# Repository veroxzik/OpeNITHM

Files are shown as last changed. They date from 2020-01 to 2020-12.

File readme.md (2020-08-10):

# OpeNITHM

This repository contails files related to OpeNITHM.

Firmware, schematics, board layout, and CAD files are included in this repo. Please see the CAD directory for the original 3d printed version, or the v2-cad directory for the laser cut version. 

## List of Electronics

OpeNITHM is designed for the Teensy LC.

#### Why use Teensy and not Arduino?

The biggest reason is that Teensy has built in capacitive sensing, which is how OpeNITHM fuctions. You have to fake it on Arduino using very controlled analog reads, and it is nowhere near as sensitive. In my (VXZK's) experience, it was simply impossible to use an Arduino to do the capacitive sensing required for this project.

I chose the Teensy LC as it is the lowest cost Teensy model available with capacitive sensing. The firmware and PCB are designed for this board alone; significant modifications may be required for any other version.

There is an alternative build using an Arduino Pro Micro and 2 MPR121s as a branch in this repo, but it is not maintained and not recommended. You're on your own with that one!

### Teensy LC Build

Links are mostly suggestions (except the Teensy, which is only officially available through the PJRC site and authorized resellers).  
(VXZK: I've heard a lot of trouble regarding good quality IR leds and phototransistors, so I've included specific links to the ones I purchased and has worked well for me.)  

The links below also assume you want to socket your Teensy and multiplexers for later use. You can solder them directly, if you'd like.  
If you are going to solder your sensors directly to the PCB, it is not necessary buy the 0.1" Pin Header, Right Angle. Otherwise, include female 0.1" sockets for your sensors (commonly referred to as Dupont connectors).  

| Part | Link | Qty |
| --- | --- |:---:|
| Teensy LC | https://www.pjrc.com/store/teensylc.html | 1 |
| Teensy LC Breakout Board | this Github, Circuit-Teensy32 folder contains gerbers | 1 |
| 74HC4051 Multiplexer Breakout Board | [Aliexpress][1] | 4 |
| 0.1" Pin Header, 1 row, 40 pos | [Aliexpress (qty 10)][2] | 2 |
| 0.1" Pin Header, Right Angle, 2 row, 24 pos | [LCSC][3] | 2 |
| 0.1" Socket, Straight, 1 row, 14 pos | [LCSC][4] | 2 |
| 0.1" Socket, Straight, 1 row, 5 pos | [LCSC][5] | 2 |
| 0.1" Socket, Straight, 1 row, 11 pos | [LCSC][6] | 2 |
| 0.1" Socket, Straight, 1 row, 8 pos | [LCSC][7] | 2 |
| 51k ohm Resistor, 1/6W or 1/8W | LCSC or Aliexpress | 6 |
| 33 ohm Resistor, 1/4W, 1/6W, or 1/8W | LCSC or Aliexpress | 3 |
| 1m WS2812B RGB 5V LED Strip, 30LED Per Meter | [Aliexpress][8] | 1 |
| IR LED and Phototransistor | [Ebay (Qty 20 pairs)][9] | 6 |

[1]: https://www.aliexpress.com/item/32807771098.html
[2]: https://www.aliexpress.com/item/665534073.html
[3]: https://lcsc.com/product-detail/New-Arrivals_XFCN-PZ254R-12-24P_C492440.html
[4]: https://lcsc.com/product-detail/Pin-Header-Female-Header_Boom-Precision-Elec-Female-header-2-54-1-14P_C52711.html
[5]: https://lcsc.com/product-detail/Pin-Header-Female-Header_Boom-Precision-Elec-2-54mm-1-5p-Female-header_C50950.html
[6]: https://lcsc.com/product-detail/Pin-Header-Female-Header_Changjiang-Connectors-A2541HWV-11P_C225508.html
[7]: https://lcsc.com/product-detail/Pin-Header-Female-Header_Boom-Precision-Elec-2-54mm-1-8P-Straight-Female-header_C27438.html
[8]: https://www.aliexpress.com/item/2036819167.html
[9]: https://www.ebay.com/itm/40pcs-5mm-Infrared-LED-940nm-Emitter-Diode-and-IR-Receiver-Set/252235145540

## Board Revision and Sensors

As of 2020-07-17, the recommended board version is v2.1, which features inputs for 32 sensors. This best replicates the feeling of the arcade. Previous versions used 16 sensors. If you still wish to make a 16 key version, you can order the v2.1 but only populate two of the multiplexers. This is not really recommended.

### Older versions

For v2.0 and v1.1, bridge pins 17 and 24 for best throughput of RGB lighting and select the appropriate setting in `Config.h`.

## Installing on Teensy LC

**NOTE:** This firmware is *only* written to work for the Teensy LC. Do *not* use Teensy 2.0, Teensy 3.x, or Teensy 4.x

Locate your `arduino` folder (usually `C:\Program Files (x86)\arduino`).

#### I have a fresh install of Teensyduino, or have never modified my USB profiles

Copy `Firmware/Teensy/boards.txt` to `arduino\hardware\teensy\avr\` and overwrite the existing.

Copy `Firmware/Teensy/teensy3` to `arduino\hardware\teensy\avr\cores\teensy3` and overwrite any conflicts.

Copy `Firmware/FastLED/WS2812Serial.cpp` and `Firmware/FastLED/WS2812Serial.h` to `arduino\hardware\teensy\avr\libraries\WS2812Serial` and overwrite the existing.

Copy `Firmware/FastLED/FastLED.cpp` and `Firmware/FastLED/FastLED.h` to `[My Documents]\Arduino\libraries\FastLED\` and overwrite the existing.

#### I am applying the changes manually

See [the firmware readme](Firmware/README.md) for more information.

## Configuring the Firmware and IDE

There are a number of options built into the firmware to give you flexibility in your implementation. These are presented as preprocessor defines that can be commented and uncommented to fit.

All user-editable defines are in `Config.h`, see the comments for additional information.

`PinConfig.h` contains the defintions of each pin. This does not need to be edited if using the gerbers from this repo.

If you do not have the FastLED library installed, do so though the `Tools->Manage Libraries` menu. You will also need the WS2812Serial library, which should be installed when you install Teensyduino.

#### Compiling

Select `Teensy LC` from `Tools->Board`, then select `Serial + NKRO Keyboard`.

Prior to compilation, review the (numerous) options available to the end user in `Config.h`. Comment and uncomment the corresponding options that match your setup.

## Running the Software

#### Configuring

To be revised.

#### Power On

To be revised.

#### Output

By default, the program will run in NKRO Keyboard mode. The specific keyboard keys are set in `USBOutput.cpp`, but are listed here in order of left to right:
```
a z s x d c f v g b h n j m k ,
```
When a second finger touches the pad, the following keys are pressed in order of left to right
```
1 q 2 w 3 e 4 r 5 t 6 y 7 u 8 i
```

By default, the air sensor functions as follows:
- `Home` is held as long as any sensor is triggered and released when there are no sensors triggered.
- `End` is pressed when any motion is detected, as long as the hand was previously in front of the sensors.
- `Page Up` is pressed and released when the sensor detections movement upwards.
- `Page Down` is pressed and released when the sensor detections movement downwards.

If `#define IR_SENSOR_KEY` is uncommented, each air sensor will report back individually. The default binding from bottom to top is:
```
/ . ' ; ] [
```
Per US QWERTY layout.

## Credits

Thanks to SpaghettiSnail for the LED Support Peg model!

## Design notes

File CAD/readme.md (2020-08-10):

## List of Hardware

In the `CAD\STL` folder, you will find numerous parts that must be 3D printed.

Please check out [the wiki](https://github.com/veroxzik/OpeNITHM/wiki/File-Explanation) for more information.

| Part | Qty |
| --- |:---:|
| Center Frame | 1 |
| Right Frame | 1 |
| Left Frame | 1 |
| Key Dual 2.5mm **OR** Key Dual 3mm<sup>1</sup> | 16 |
| LED Support Peg | 16 |
| Sensor Rail | 2 |
| Sensor Spacer Left<sup>2</sup> | 1 |
| Sensor Base Left<sup>2</sup> **OR** Integrated Sensor Base Left<sup>2</sup> | 1 |
| Sensor Cover Left<sup>2</sup> | 1 |
| Integrated Frame Mount Left<sup>2,3</sup> | 1 |

**NOTES:** 
1. Use 2.5mm for 3/32" and 3mm for 1/8" acrylic. 
2. Print out mirrored version of these parts as well.
3. Only print the frame mount if you are using the integrated sensor.

The non-printed materials and hardware include:

| Part | Qty |
| --- |:---:|
| 4-40 Flat Head Screw, length 3/16" to 5/16" will work **OR** M3 equivalent | 2 |
| Top Acrylic Plate<sup>1</sup> (472mm x 112mm) | 1 |
| Key Acrylic<sup>1</sup> (103.5mm x 26mm) | 16  |
| Copper Tape, cut into rectangles 95mm x 26mm | 16  |

**NOTES:**
1. Use 2.5mm (3/32") **OR** 3mm (1/8") acrylic. Use the same acrylic for top plate and keys.

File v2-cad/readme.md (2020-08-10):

# OpeNITHM

This repository contails files related to the second generation, laser cut case.

## Fasteners

| Part | Link | Qty |
| --- | --- | :---:|
| 25mm M3 Female-Female hex standoffs | [McMaster][1] | 10  |
| 10 or 11mm M3 hex standoffs | | 8 |
| 20mm M5 screw | | 4 |
| M5 hex nuts | | 4 |
| 8mm M3 Black-Oxide Alloy Steel Hex Drive Flat Head Screw | [McMaster][2] | 18 |
| 8mm M3 18-8 Stainless Steel Hex Drive Flat Head Screw | [McMaster][3] | 8 |
| 8mm M3 316 Stainless Steel Button Head Hex Drive Screws | [McMaster][4] | 14 |
| M2.5 hex nuts ||2|
| 25mm M2.5 screw ||2|
| Copper Tape, cut into rectangles 95mm x 26mm | | 16  |

[1]: https://www.mcmaster.com/95947A018
[2]: https://www.mcmaster.com/91294A128
[3]: https://www.mcmaster.com/92125A128
[4]: https://www.mcmaster.com/94500A222

## Electronics changes

As opposed to the original design, this design uses 31 LEDS, 60 per meter spacing (instead of 30). https://www.aliexpress.com/item/2036819167.html

Additionally, this has a center mounted usb-c connector, which is simply https://www.adafruit.com/product/4090, with a small microusb connector soldered to it, connected to the teensy.

## Notes

I've listed the acrylic as either 1.5mm, 3mm, or 5.6mm, but 5mm should work fine.
You may have to adjust for kerf, your laser and my laser act differently.
Red lines are always cut, black is always etch.
If you do not make a shield layer and cover it with foil, you may end up with a ton of noise. Capsense is weird. I'm sorry.

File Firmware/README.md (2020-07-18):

**NOTE** The line numbers may not correspond to your version of Teenyduino, they are only for reference.

(It is easier to copy and paste from the files in `Firmware/Teensy` instead of through here, the below is just for reference.)

Add `usb_nkro.c` and `usb_nkro.h` to `arduino\hardware\teensy\avr\cores\teensy3`

In `arduino\hardware\teesny\avr\boards.txt` add lines 1175-1179

```c
1175    teensyLC.menu.usb.nkrokeyboard=NKRO Keyboard
1176    teensyLC.menu.usb.nkrokeyboard.build.usbtype=USB_NKRO
1177    teensyLC.menu.usb.nkrokeyboard.fake_serial=teensy_gateway
1178    teensyLC.menu.usb.serialnkrokeyboard=Serial + NKRO Keyboard
1179    teensyLC.menu.usb.serialnkrokeyboard.build.usbtype=USB_SERIAL_NKRO

In `arduino\hardware\teensy\avr\cores\teensy3\WProgram.h` add line 59

```c
58    #include "usb_joystick.h"
59    #include "usb_nkro.h"
60    #include "usb_midi.h"
```

In `arduino\hardware\teensy\avr\cores\teensy3\usb_inst.cpp` add lines 75-77

```c
72    usb_serial_class Serial;
73    #endif
74    
75    #ifdef NKRO_INTERFACE
76    usb_nkro_class Nkro;
77    #endif
78    
79    #else // F_CPU < 20 MHz
```

In `arduino\hardware\teensy\avr\cores\teensy3\usb_dev.h` add lines 93-98

```c
90    extern volatile uint8_t keyboard_leds;
91    #endif
92    
93    #ifdef NKRO_INTERFACE
94    extern uint8_t nkro_report_data[NKRO_SIZE];
95    extern uint8_t nkro_protocol;
96    extern uint8_t nkro_idle_config;
97    extern uint8_t nkro_idle_count;
98    #endif
99    
100   #ifdef MIDI_INTERFACE
```

In `arduino\hardware\teensy\avr\cores\teensy3\usb_desc.h` add lines 868-948

```c
866      #define ENDPOINT15_CONFIG	ENDPOINT_TRANSMIT_ONLY
867    
868    #elif defined(USB_NKRO)
869      #define VENDOR_ID		0x16C0
870      #define PRODUCT_ID		0x04D0
871      #define MANUFACTURER_NAME	{'T','e','e','n','s','y','d','u','i','n','o'}
872      #define MANUFACTURER_NAME_LEN	11
873      #define PRODUCT_NAME		{'N','K','R','O',' ','K','e','y','b','o','a','r','d'}
874     #define PRODUCT_NAME_LEN	13
875      #define EP0_SIZE		64
876      #define NUM_ENDPOINTS         5
877      #define NUM_USB_BUFFERS	14
878      #define NUM_INTERFACE		4
879      #define SEREMU_INTERFACE      1	// Serial emulation
880      #define SEREMU_TX_ENDPOINT    1
881      #define SEREMU_TX_SIZE        64
882      #define SEREMU_TX_INTERVAL    1
883      #define SEREMU_RX_ENDPOINT    2
884      #define SEREMU_RX_SIZE        32
885      #define SEREMU_RX_INTERVAL    2
886      #define KEYBOARD_INTERFACE    0	// Keyboard
887      #define KEYBOARD_ENDPOINT     3
888      #define KEYBOARD_SIZE         8
889      #define KEYBOARD_INTERVAL     1
890      #define KEYMEDIA_INTERFACE    2	// Keyboard Media Keys
891      #define KEYMEDIA_ENDPOINT     4
892      #define KEYMEDIA_SIZE         8
893      #define KEYMEDIA_INTERVAL     4
894      #define NKRO_INTERFACE        3	// NKRO Keyboard
895      #define NKRO_ENDPOINT         5
896      #define NKRO_SIZE             32
897      #define NKRO_REPORT_KEYS		( NKRO_SIZE - 1 )
898      #define NKRO_INTERVAL         1
899      #define ENDPOINT1_CONFIG	ENDPOINT_TRANSMIT_ONLY
900      #define ENDPOINT2_CONFIG	ENDPOINT_RECEIVE_ONLY
901      #define ENDPOINT3_CONFIG	ENDPOINT_TRANSMIT_ONLY
902      #define ENDPOINT4_CONFIG	ENDPOINT_TRANSMIT_ONLY
903      #define ENDPOINT5_CONFIG	ENDPOINT_TRANSMIT_ONLY
904      #define ENDPOINT6_CONFIG	ENDPOINT_TRANSMIT_ONLY
905
906    #elif defined(USB_SERIAL_NKRO)
907      #define VENDOR_ID		0x16C0
908      #define PRODUCT_ID		0x0487
909      #define DEVICE_CLASS		0xEF
910      #define DEVICE_SUBCLASS	0x02
911      #define DEVICE_PROTOCOL	0x01
912      #define MANUFACTURER_NAME	{'T','e','e','n','s','y','d','u','i','n','o'}
913      #define MANUFACTURER_NAME_LEN	11
914      #define PRODUCT_NAME		{'S','e','r','i','a','l','/','N','K','R','O',' ','K','e','y','b','o','a','r','d'}
915      #define PRODUCT_NAME_LEN	20
916      #define EP0_SIZE		64
917      #define NUM_ENDPOINTS         6
918      #define NUM_USB_BUFFERS	14
919      #define NUM_INTERFACE		5
920      #define CDC_IAD_DESCRIPTOR	1
921      #define CDC_STATUS_INTERFACE	0
922      #define CDC_DATA_INTERFACE	1	// Serial
923      #define CDC_ACM_ENDPOINT	2
924      #define CDC_RX_ENDPOINT       3
925      #define CDC_TX_ENDPOINT       4
926      #define CDC_ACM_SIZE          16
927      #define CDC_RX_SIZE           64
928      #define CDC_TX_SIZE           64
929      #define KEYBOARD_INTERFACE    2	// Keyboard
930      #define KEYBOARD_ENDPOINT     1
931      #define KEYBOARD_SIZE         8
932      #define KEYBOARD_INTERVAL     1
933      #define KEYMEDIA_INTERFACE    3	// Keyboard Media Keys
934      #define KEYMEDIA_ENDPOINT     5
935      #define KEYMEDIA_SIZE         8
936      #define KEYMEDIA_INTERVAL     4
937      #define NKRO_INTERFACE        4	// NKRO Keyboard
938      #define NKRO_ENDPOINT         6
939      #define NKRO_SIZE             32
940      #define NKRO_REPORT_KEYS		( NKRO_SIZE - 1 )
941      #define NKRO_INTERVAL         1
942      #define ENDPOINT1_CONFIG	ENDPOINT_TRANSMIT_ONLY
943      #define ENDPOINT2_CONFIG	ENDPOINT_TRANSMIT_ONLY
944      #define ENDPOINT3_CONFIG	ENDPOINT_RECEIVE_ONLY
945      #define ENDPOINT4_CONFIG	ENDPOINT_TRANSMIT_ONLY
946      #define ENDPOINT5_CONFIG	ENDPOINT_TRANSMIT_ONLY
947      #define ENDPOINT6_CONFIG	ENDPOINT_TRANSMIT_ONLY
948    #endif
949    
950    #ifdef USB_DESC_LIST_DEFINE
```

In `arduino\hardware\teensy\avr\cores\teensy3\usb_desc.c` add lines 239-265

```c
236    };
237    #endif
238    
239    #ifdef NKRO_INTERFACE
240    // Via https://dawnmist.dreamwidth.org/1250.html
241    static uint8_t nkro_hid_report_desc[] = {
242            0x05, 0x01, // Usage Page (Generic Desktop),
243            0x09, 0x06, // Usage (Keyboard),
244            0xA1, 0x01, // Collection (Application),
245            // bitmap of modifiers
246            0x75, 0x01, // Report Size (1),
247            0x95, 0x08, // Report Count (8),
248            0x05, 0x07, // Usage Page (Key Codes),
249            0x19, 0xE0, // Usage Minimum (224),
250            0x29, 0xE7, // Usage Maximum (231),
251            0x15, 0x00, // Logical Minimum (0),
252            0x25, 0x01, // Logical Maximum (1),
253            0x81, 0x02, // Input (Data, Variable, Absolute), ;Modifier byte
254            // bitmap of keys
255            0x95, NKRO_REPORT_KEYS*8, // Report Count (),
256            0x75, 0x01, // Report Size (1),
257            0x15, 0x00, // Logical Minimum (0),
258            0x25, 0x01, // Logical Maximum(1),
259            0x05, 0x07, // Usage Page (Key Codes),
260            0x19, 0x00, // Usage Minimum (0),
261            0x29, NKRO_REPORT_KEYS*8-1, // Usage Maximum (),
262            0x81, 0x02, // Input (Data, Variable, Absolute),
263            0xc0 // End Collection
264    };
265    #endif
266    
267    #ifdef JOYSTICK_INTERFACE
268    #if JOYSTICK_SIZE == 12
```

In `arduino\hardware\teensy\avr\cores\teensy3\usb_desc.c` add lines 603-610 and modify line 612

```c
600    #define MULTITOUCH_INTERFACE_DESC_SIZE	0
601    #endif
602    
603    // Via https://dawnmist.dreamwidth.org/1250.html
604    #define NKRO_INTERFACE_DESC_POS	MULTITOUCH_INTERFACE_DESC_POS+MULTITOUCH_INTERFACE_DESC_SIZE
605    #ifdef  NKRO_INTERFACE
606    #define NKRO_INTERFACE_DESC_SIZE	9+9+7
607    #define NKRO_HID_DESC_OFFSET	NKRO_INTERFACE_DESC_POS+9
608    #else
609    #define NKRO_INTERFACE_DESC_SIZE	0
610    #endif
611    
612    #define CONFIG_DESC_SIZE		NKRO_INTERFACE_DESC_POS+NKRO_INTERFACE_DESC_SIZE
613    
614    
615    
616    // **************************************************************
```

In `arduino\hardware\teensy\avr\cores\teensy3\usb_desc.c` add lines 1131-1158

```c
1129   #endif // JOYSTICK_INTERFACE
1130   
1131   #ifdef NKRO_INTERFACE
1132           // interface descriptor, USB spec 9.6.5, page 267-269, Table 9-12
1133           9,                                      // bLength
1134           4,                                      // bDescriptorType
1135           NKRO_INTERFACE,                         // bInterfaceNumber
1136           0,                                      // bAlternateSetting
1137           1,                                      // bNumEndpoints
1138           0x03,                                   // bInterfaceClass (0x03 = HID)
1139           0x00,                                   // bInterfaceSubClass (0x01 = Boot)
1140           0x00,                                   // bInterfaceProtocol (0x01 = Keyboard)
1141           0,                                      // iInterface
1142           // HID interface descriptor, HID 1.11 spec, section 6.2.1
1143           9,                                      // bLength
1144           0x21,                                   // bDescriptorType
1145           0x11, 0x01,                             // bcdHID
1146           0,                                      // bCountryCode
1147           1,                                      // bNumDescriptors
1148           0x22,                                   // bDescriptorType
1149           LSB(sizeof(nkro_hid_report_desc)),      // wDescriptorLength
1150           MSB(sizeof(nkro_hid_report_desc)),
1151           // endpoint descriptor, USB spec 9.6.6, page 269-271, Table 9-13
1152           7,                                      // bLength
1153           5,                                      // bDescriptorType
1154           NKRO_ENDPOINT | 0x80,                   // bEndpointAddress
1155           0x03,                                   // bmAttributes (0x03=intr)
1156           NKRO_SIZE, 0,                           // wMaxPacketSize
1157           NKRO_INTERVAL,                          // bInterval
1158   #endif // NKRO_INTERFACE
1159   
1160   #ifdef MTP_INTERFACE
```

In `arduino\hardware\teensy\avr\cores\teensy3\usb_desc.c` add lines 1602-1605

```c
1600           {0x2100, MULTITOUCH_INTERFACE, config_descriptor+MULTITOUCH_HID_DESC_OFFSET, 9},
1601   #endif
1602   #ifdef NKRO_INTERFACE
1603           {0x2200, NKRO_INTERFACE, nkro_hid_report_desc, sizeof(nkro_hid_report_desc)},
1604           {0x2100, NKRO_INTERFACE, config_descriptor+NKRO_HID_DESC_OFFSET, 9},
1605   #endif
1606   #ifdef MTP_INTERFACE
```

In `arduino\hardware\teensy\avr\boards.txt` add lines 1175-1177
```
1174    teensyLC.menu.usb.flightsim.fake_serial=teensy_gateway
1175    teensyLC.menu.usb.nkrokeyboard=NKRO Keyboard
1176    teensyLC.menu.usb.nkrokeyboard.build.usbtype=USB_NKRO
1177    teensyLC.menu.usb.nkrokeyboard.fake_serial=teensy_gateway
1178    teensyLC.menu.usb.disable=No USB
```

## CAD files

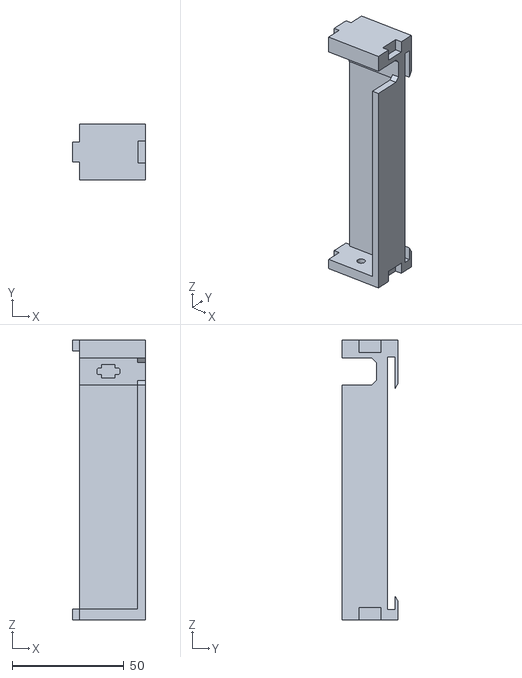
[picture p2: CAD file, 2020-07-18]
CAD/3D Printed Build/STL/Key - Dual Layer/Key-Dual-3mm.stl
32.5 x 25.0 x 125.0

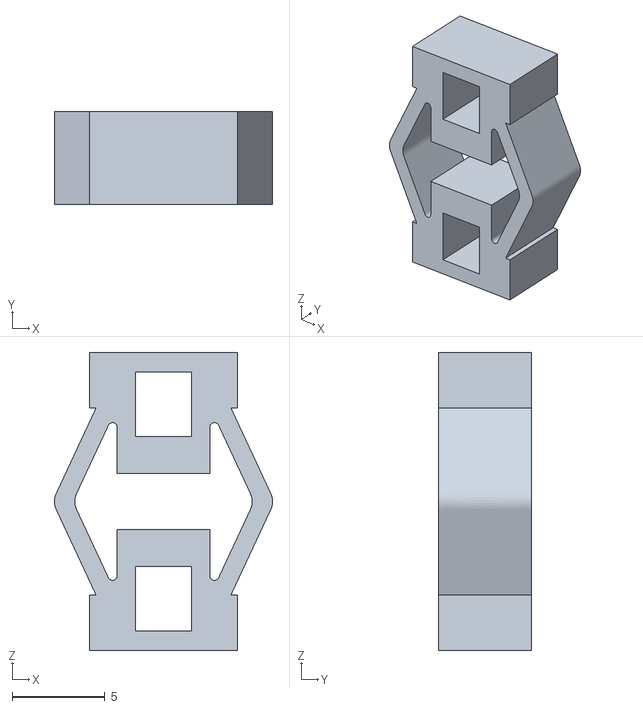
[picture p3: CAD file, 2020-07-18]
CAD/3D Printed Build/STL/Key - Single Layer/LED Clamp.stl
11.8 x 5.00 x 16.1

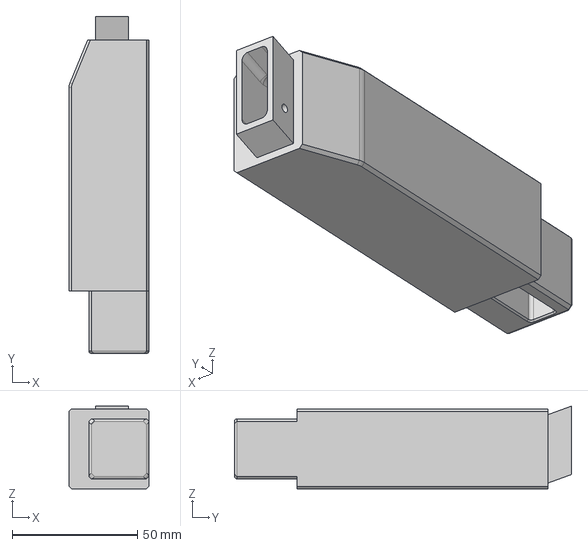
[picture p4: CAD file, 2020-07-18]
CAD/STEP/Integrated Sensor Base Left.step
31.9 x 134.4 x 33.0 mm

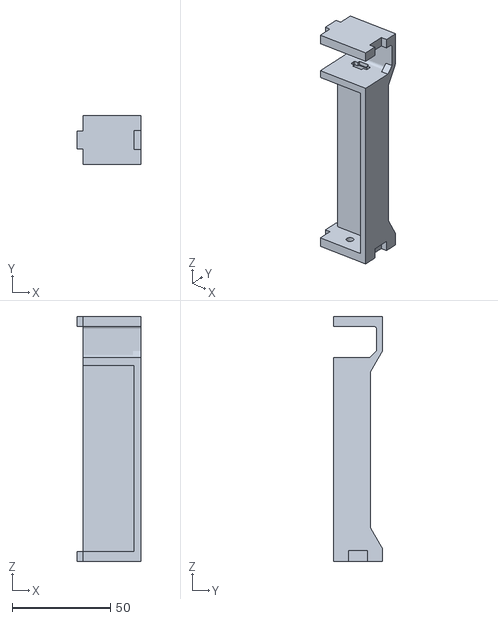
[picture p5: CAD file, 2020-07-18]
CAD/3D Printed Build/STL/Key - Single Layer/Key-Single-0.625in.stl
32.5 x 25.0 x 125.0

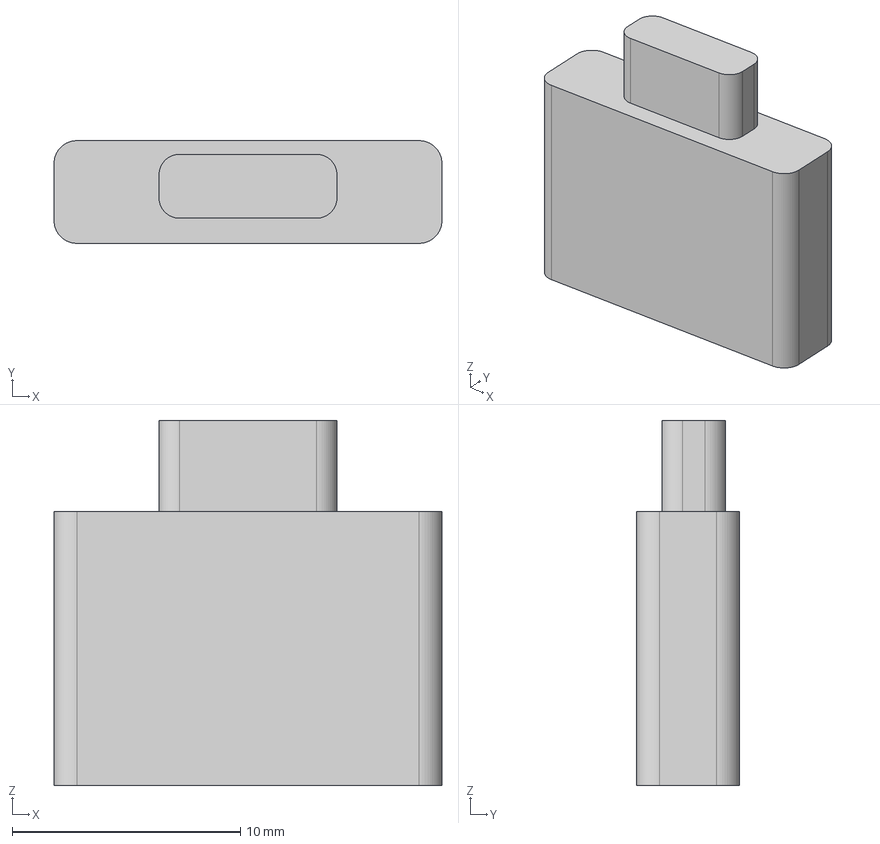
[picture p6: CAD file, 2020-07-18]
CAD/STEP/LED Retaining Peg.step
17.0 x 4.50 x 16.0 mm

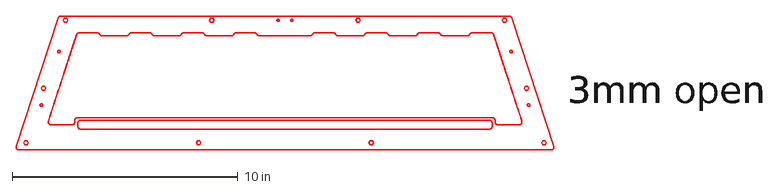
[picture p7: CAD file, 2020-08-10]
v2-cad/shield_3mm_black.dxf
3mm open

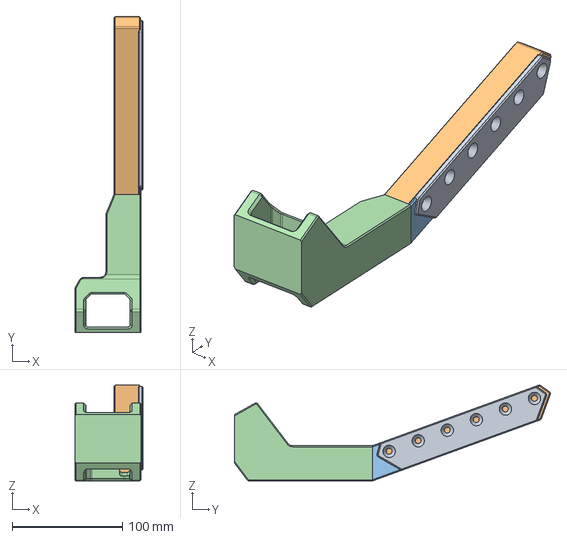
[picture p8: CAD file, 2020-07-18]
CAD/STEP/Sensor Stand Left.step
62.0 x 286.0 x 86.7 mm

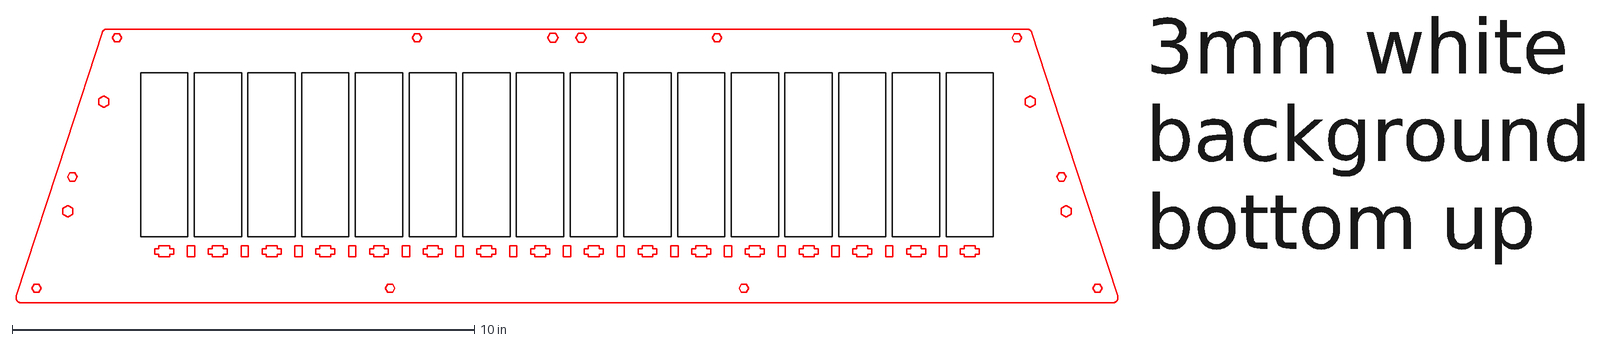
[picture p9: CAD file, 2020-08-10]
v2-cad/key_layer_3mm_white.dxf
3mm white background bottom up

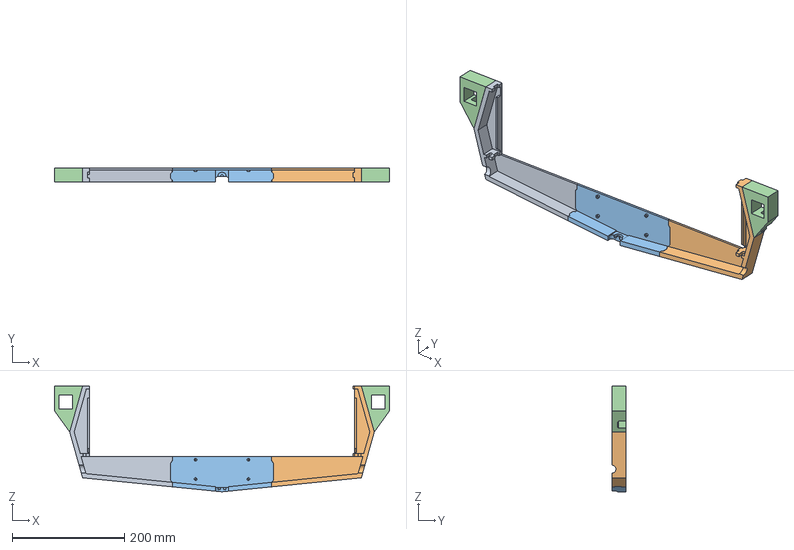
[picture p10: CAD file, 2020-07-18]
CAD/STEP/Frame.step
596.0 x 25.0 x 188.0 mm

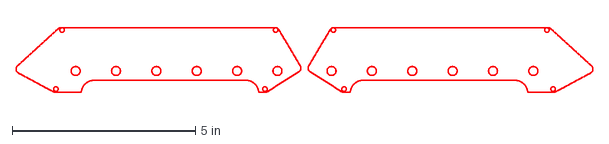
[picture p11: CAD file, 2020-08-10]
v2-cad/side_fronts_black_paper.dxf
15.8 x 1.77 in

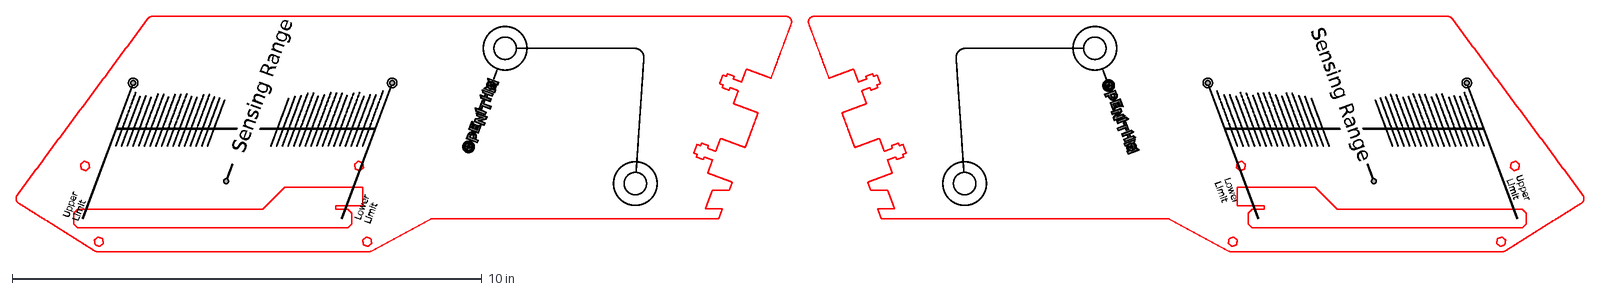
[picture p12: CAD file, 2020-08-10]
v2-cad/side_wings_5.6mm_smoke.dxf
Upper Limit
Sensing Range
Lower Limit

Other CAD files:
v2-cad/all_layers.dxf
CAD/3D Printed Build/STL/Key - Dual Layer/Key-Dual-2.5mm.stl
CAD/3D Printed Build/STL/Key - Dual Layer/LED Support Peg.stl
CAD/3D Printed Build/STL/Key - Single Layer/Key-Single-3mm.stl
CAD/STEP/Key-Dual-3mm.step
CAD/STEP/Key-Dual-2.5mm.step
v2-cad/key_layer_3mm_p95_matte_clear.dxf
CAD/3D Printed Build/Fusion 360/Key-Dual-2.5mm v4.f3d
CAD/3D Printed Build/Fusion 360/Key-Dual-3mm v2.f3d
CAD/3D Printed Build/Fusion 360/Key-Single-0.625in v6.f3d
CAD/3D Printed Build/Fusion 360/Key-Single-3mm v13.f3d
CAD/3D Printed Build/Fusion 360/LED Support Peg v1.f3d
v2-cad/black_paper_foil_cover.dxf
v2-cad/bottom_3mm_black.dxf
v2-cad/case-model.obj
v2-cad/interior_case_bottom_3mm_black.dxf
v2-cad/interior_case_mid_3mm_black.dxf
v2-cad/interior_case_top_5.6mm_black.dxf
v2-cad/light_pipe_3mm_clear.dxf
v2-cad/openithm_case.3dm
v2-cad/shield_interior_3mm_MDF.dxf
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

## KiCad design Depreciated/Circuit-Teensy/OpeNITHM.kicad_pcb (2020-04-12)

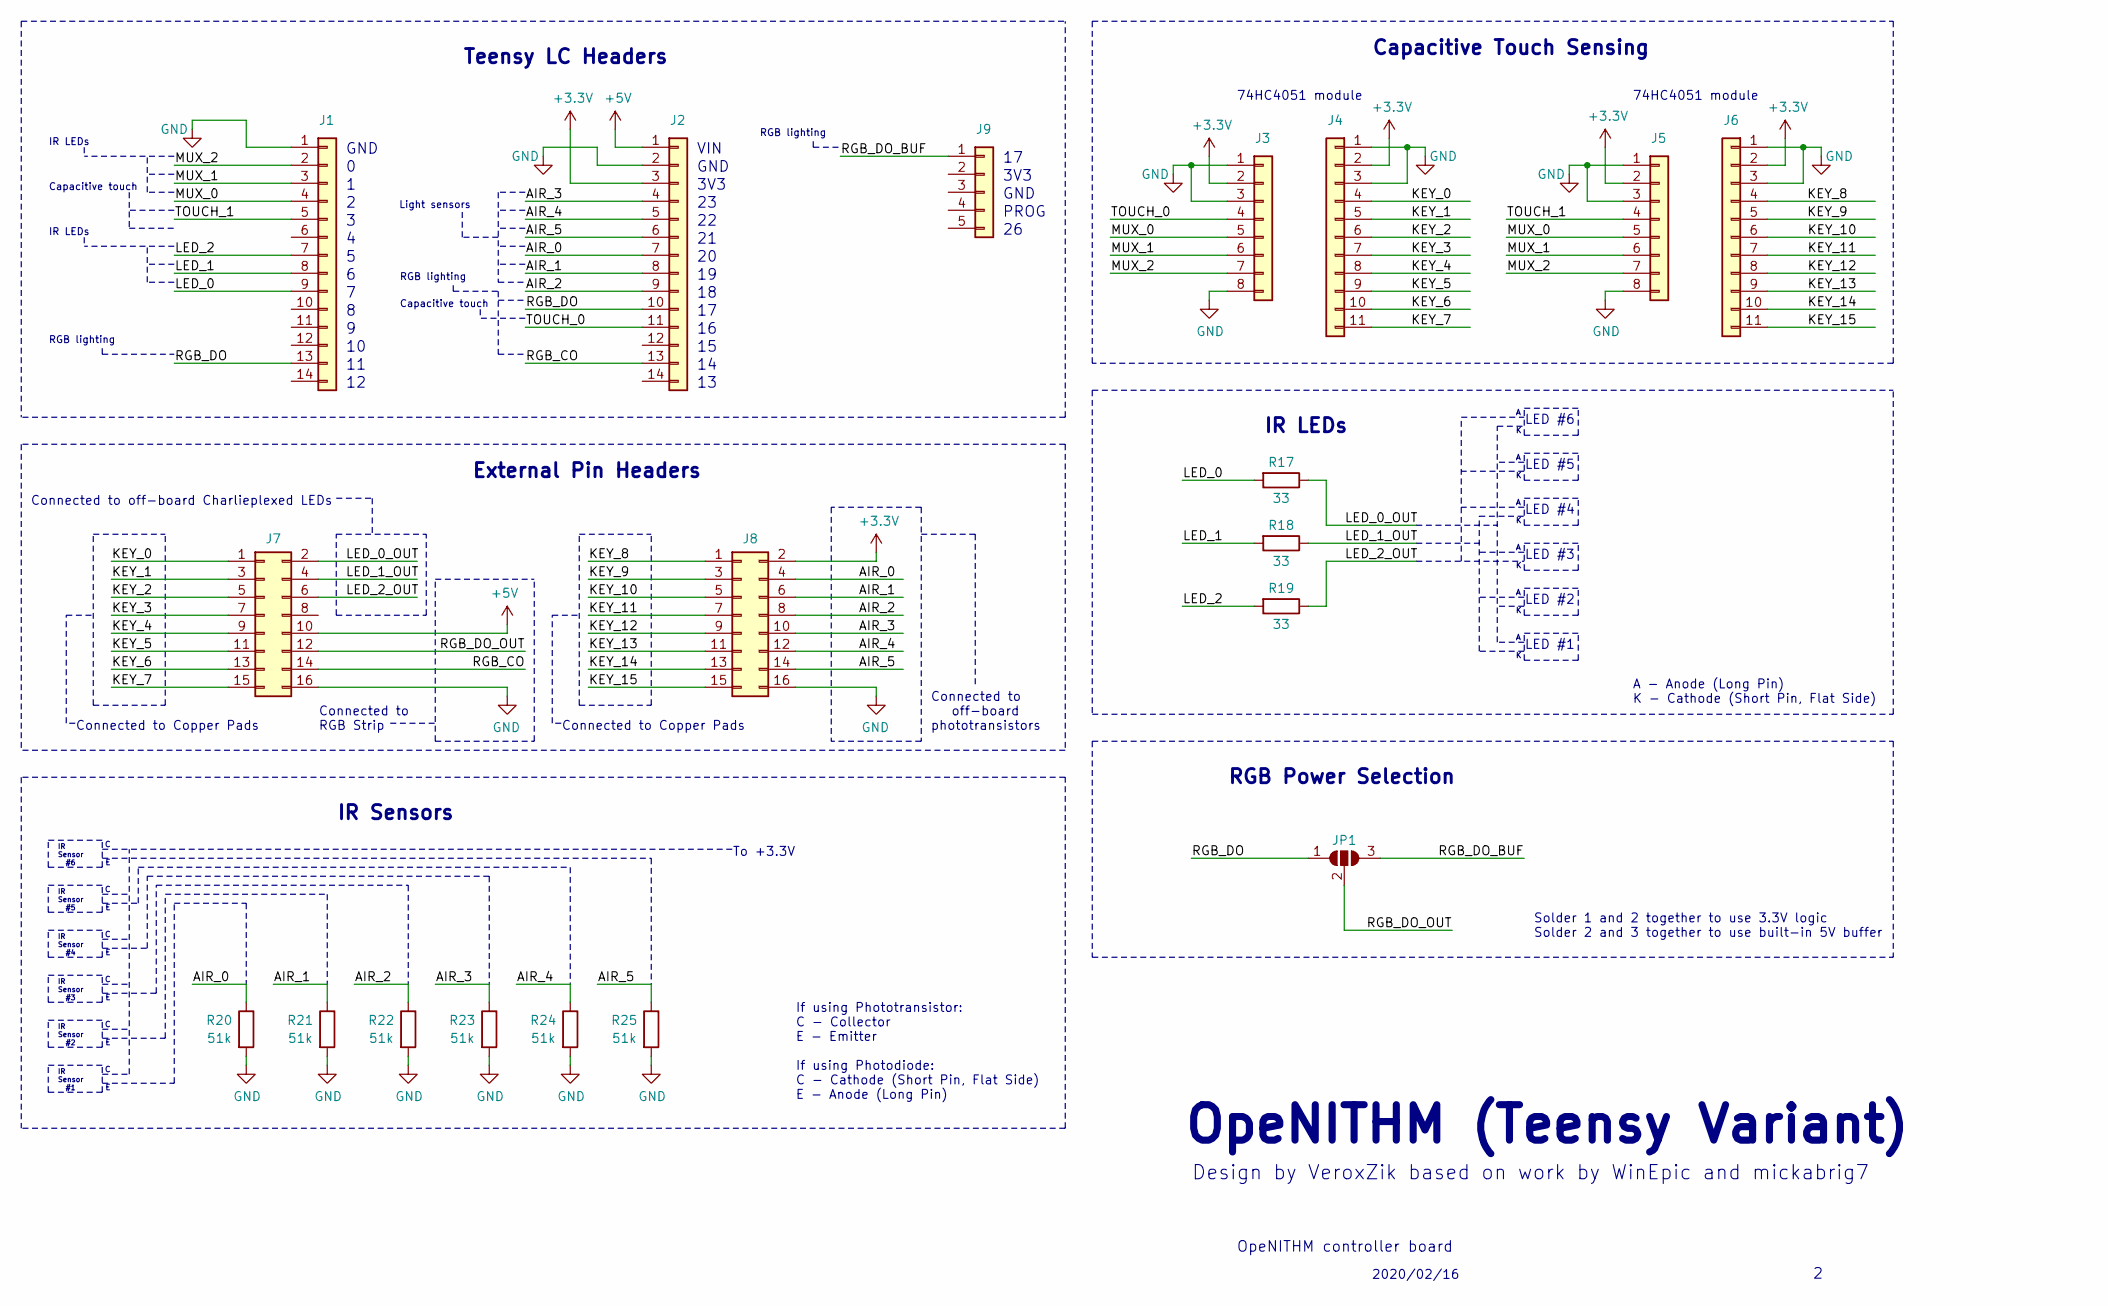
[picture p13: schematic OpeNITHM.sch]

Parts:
J1, J2: Conn_01x14; PinSocket_1x14_P2.54mm_Vertical
J3, J5: Conn_01x08; PinSocket_1x08_P2.54mm_Vertical
J4, J6: Conn_01x11; PinSocket_1x11_P2.54mm_Vertical
J7, J8: Conn_02x08_Odd_Even; PinHeader_2x08_P2.54mm_Horizontal
J9: Conn_01x05; PinSocket_1x05_P2.54mm_Vertical
JP1: SolderJumper_3_Open; SolderJumper-3_P1.3mm_Open_RoundedPad1.0x1.5mm
R17, R18, R19: 33; R_Axial_DIN0207_L6.3mm_D2.5mm_P7.62mm_Horizontal
R20, R21, R22, R23, R24, R25: 51k; R_Axial_DIN0204_L3.6mm_D1.6mm_P5.08mm_Horizontal

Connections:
+3V3: J2.3, J3.2, J4.2, J5.2, J6.2, J8.2; also elsewhere on the board
+5V: J2.1, J7.10
/AIR_0: J2.7, J8.4, R20.1
/AIR_1: J2.8, J8.6, R21.1
/AIR_2: J2.9, J8.8, R22.1
/AIR_3: J2.4, J8.10, R23.1
/AIR_4: J2.5, J8.12, R24.1
/AIR_5: J2.6, J8.14, R25.1
/KEY_0: J4.4, J7.1; also elsewhere on the board
/KEY_1: J4.5, J7.3; also elsewhere on the board
/KEY_2: J4.6, J7.5; also elsewhere on the board
/KEY_3: J4.7, J7.7; also elsewhere on the board
/KEY_4: J4.8, J7.9; also elsewhere on the board
/KEY_5: J4.9, J7.11; also elsewhere on the board
/KEY_6: J4.10, J7.13; also elsewhere on the board
/KEY_7: J4.11, J7.15; also elsewhere on the board
/KEY_8: J6.4, J8.1; also elsewhere on the board
/KEY_9: J6.5, J8.3; also elsewhere on the board
/KEY_10: J6.6, J8.5; also elsewhere on the board
/KEY_11: J6.7, J8.7; also elsewhere on the board
/KEY_12: J6.8, J8.9; also elsewhere on the board
/KEY_13: J6.9, J8.11; also elsewhere on the board
/KEY_14: J6.10, J8.13; also elsewhere on the board
/KEY_15: J6.11, J8.15; also elsewhere on the board
/LED_0: J1.9, R17.2
/LED_0_OUT: J7.2, R17.1
/LED_1: J1.8, R18.2
/LED_1_OUT: J7.4, R18.1
/LED_2: J1.7, R19.2
/LED_2_OUT: J7.6, R19.1
/MUX_0: J1.4, J3.5, J5.5
/MUX_1: J1.3, J3.6, J5.6
/MUX_2: J1.2, J3.7, J5.7
/RGB_CO: J2.13, J7.14
/RGB_DO: J1.13, J2.10, JP1.1 (A)
/RGB_DO_BUF: J9.1, JP1.3 (B)
/RGB_DO_OUT: J7.12, JP1.2 (C)
/TOUCH_0: J2.11, J3.4
/TOUCH_1: J1.5, J5.4
GND: J1.1, J2.2, J3.1, J3.3, J3.8, J4.1, J4.3, J5.1, J5.3, J5.8, J6.1, J6.3, J7.16, J8.16, R20.2, R21.2, R22.2, R23.2, R24.2, R25.2; also elsewhere on the board

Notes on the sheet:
Capacitive Touch Sensing
Teensy LC Headers
RGB lighting
2020/02/16
OpeNITHM controller board
OpeNITHM (Teensy Variant)
Design by VeroxZik based on work by WinEpic and mickabrig7
Connected to off-board phototransistors
IR Sensors
IR LEDs
LED #1
74HC4051 module
LED #2
LED #3
LED #4
LED #5
LED #6
IR Sensor #6
GND
VIN
3V3
Capacitive touch
PROG
External Pin Headers
Connected to off-board Charlieplexed LEDs
RGB Power Selection
Connected to Copper Pads
Connected to RGB Strip
A - Anode (Long Pin) K - Cathode (Short Pin, Flat Side)
Solder 1 and 2 together to use 3.3V logic Solder 2 and 3 together to use built-in 5V buffer
To +3.3V
If using Phototransistor: C - Collector E - Emitter If using Photodiode: C - Cathode (Short Pin, Flat Side) E - Anode (Long Pin)
IR Sensor #5
IR Sensor #4
IR Sensor #3
IR Sensor #2
IR Sensor #1
Light sensors

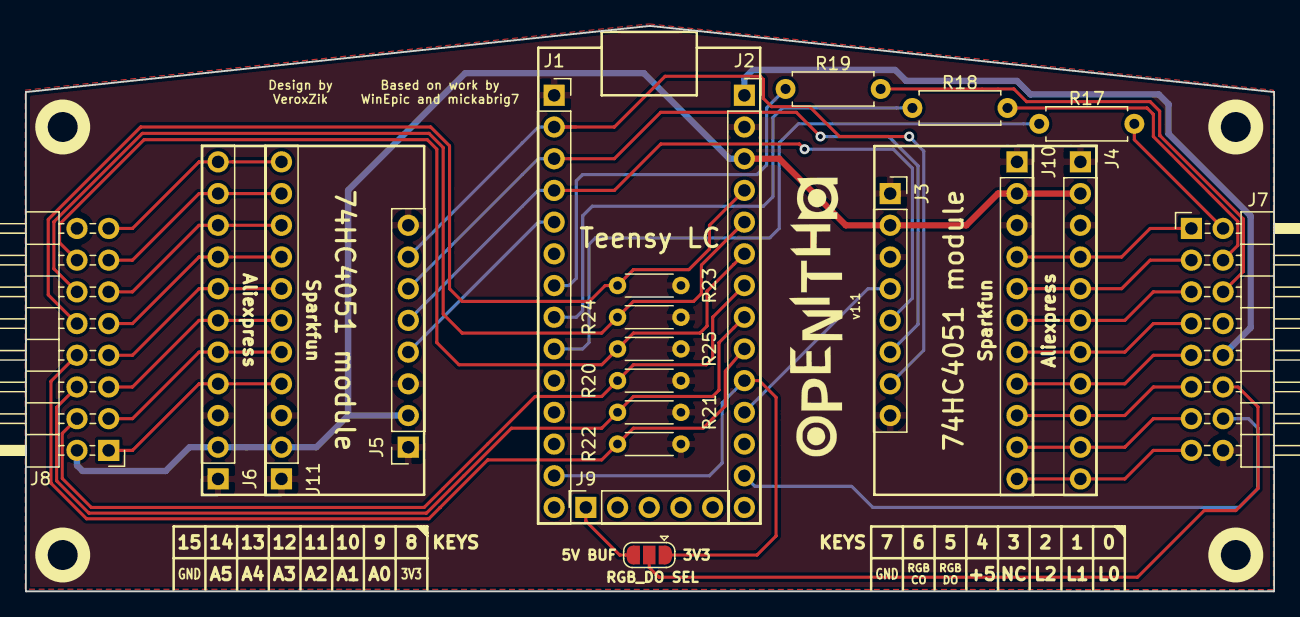
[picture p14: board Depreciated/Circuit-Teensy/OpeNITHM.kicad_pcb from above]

Board: 2 copper layers, 100.0 x 45.3 mm, 25 parts (0 on the bottom side), 40 nets.

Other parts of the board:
J10, J11: Conn_01x11; PinSocket_1x11_P2.54mm_Vertical
MH1, MH2, MH3, MH4: MountingHole; MountingHole_3.2mm_M3

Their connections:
+3V3: J10.2, J11.2; also elsewhere on the board
/KEY_0: J10.4; also elsewhere on the board
/KEY_1: J10.5; also elsewhere on the board
/KEY_2: J10.6; also elsewhere on the board
/KEY_3: J10.7; also elsewhere on the board
/KEY_4: J10.8; also elsewhere on the board
/KEY_5: J10.9; also elsewhere on the board
/KEY_6: J10.10; also elsewhere on the board
/KEY_7: J10.11; also elsewhere on the board
/KEY_8: J11.4; also elsewhere on the board
/KEY_9: J11.5; also elsewhere on the board
/KEY_10: J11.6; also elsewhere on the board
/KEY_11: J11.7; also elsewhere on the board
/KEY_12: J11.8; also elsewhere on the board
/KEY_13: J11.9; also elsewhere on the board
/KEY_14: J11.10; also elsewhere on the board
/KEY_15: J11.11; also elsewhere on the board
GND: J10.1, J10.3, J11.1, J11.3; also elsewhere on the board

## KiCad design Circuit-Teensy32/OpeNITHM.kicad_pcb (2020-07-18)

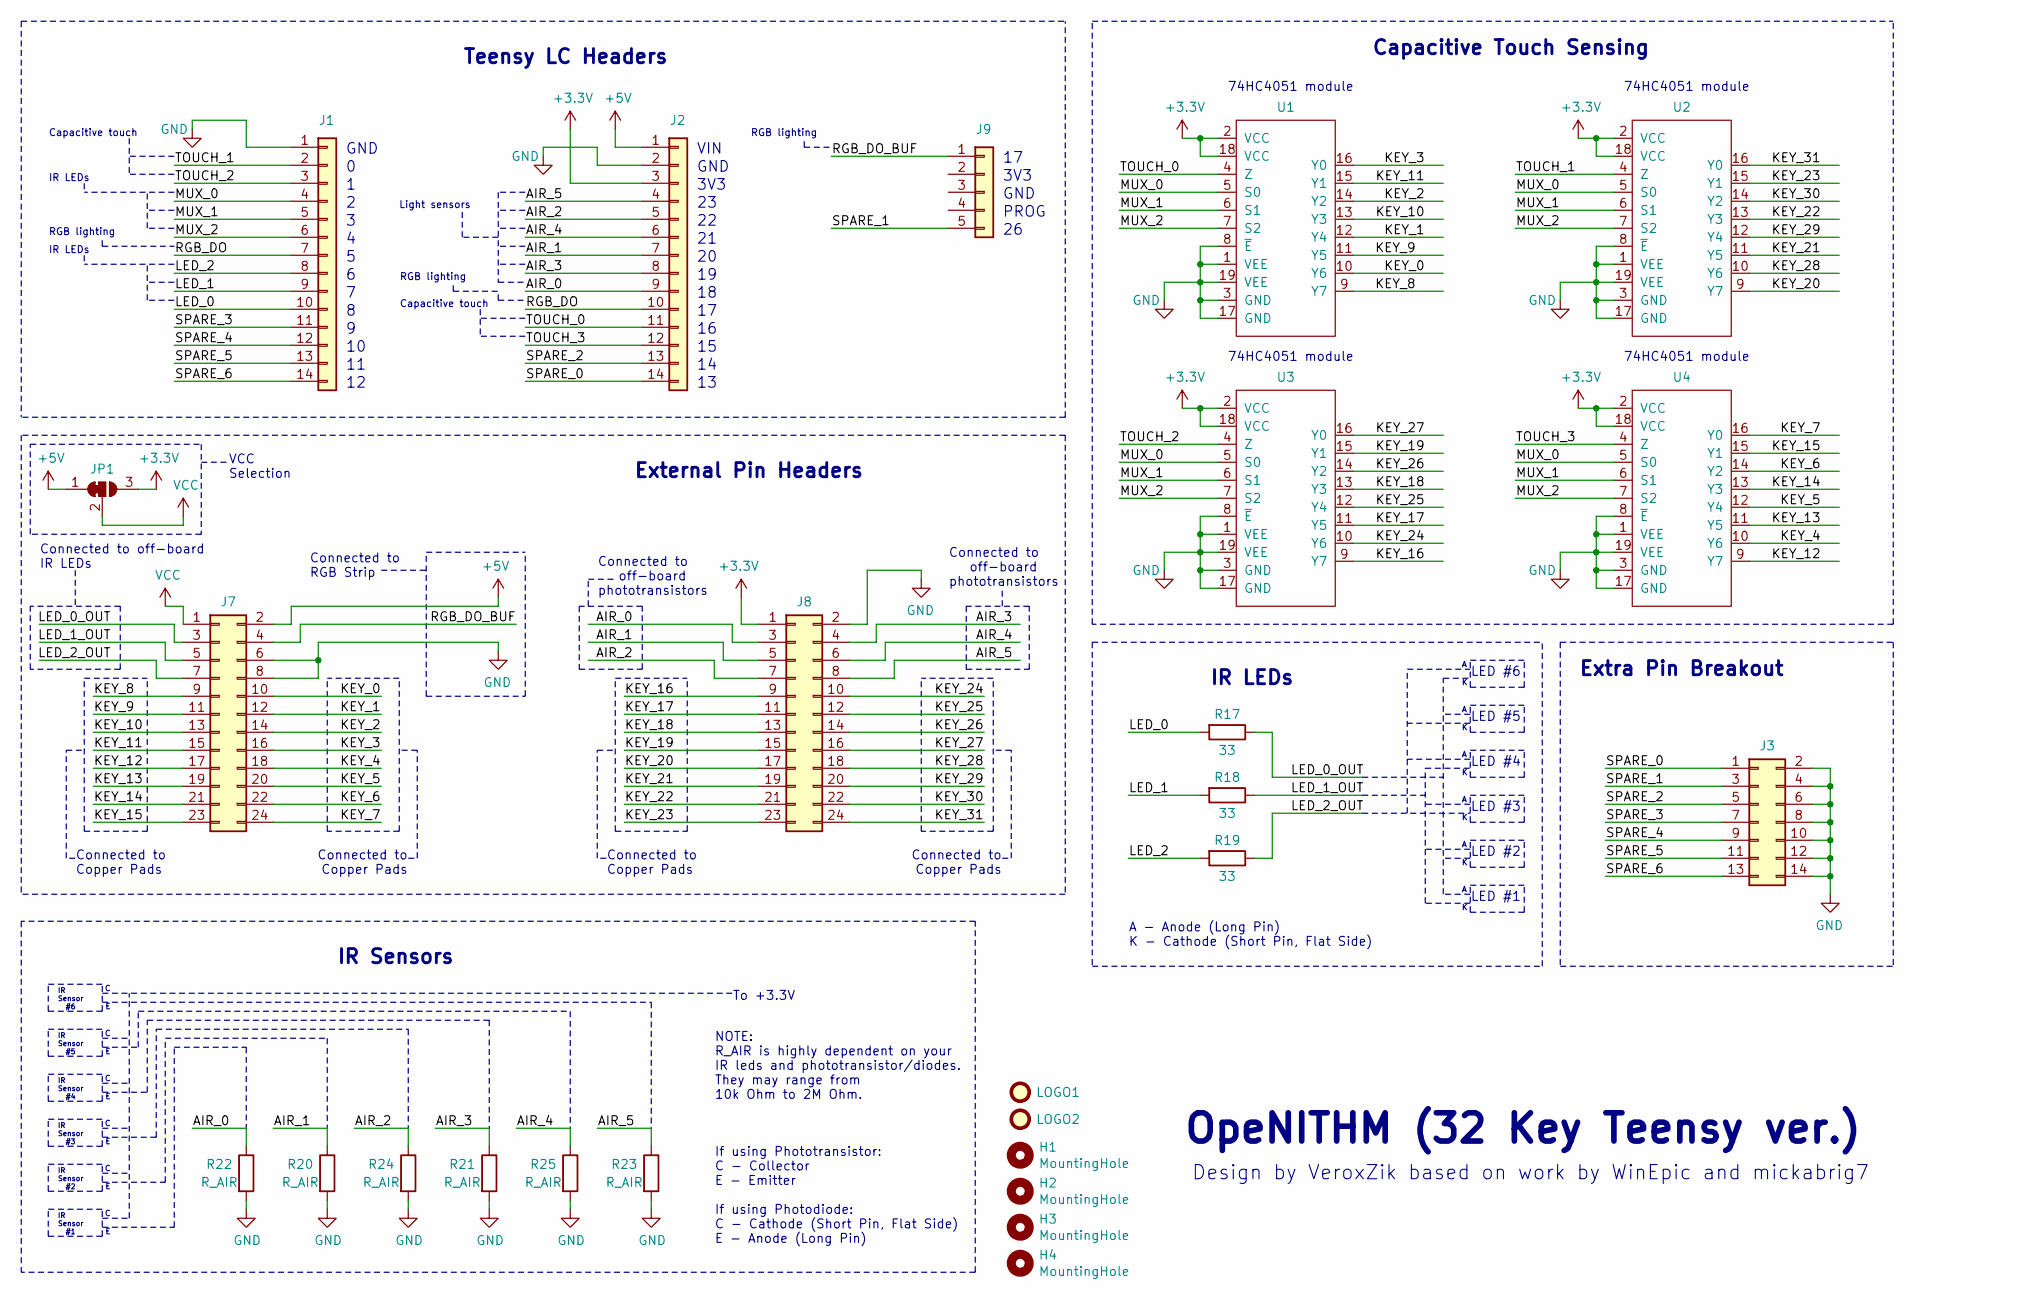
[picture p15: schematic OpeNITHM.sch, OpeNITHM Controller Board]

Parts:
H1, H2, H3, H4: MountingHole; MountingHole_3.2mm_M3_ISO14580
J1, J2: Conn_01x14; PinSocket_1x14_P2.54mm_Vertical
J3: Conn_02x07_Odd_Even; PinHeader_2x07_P2.54mm_Horizontal
J7, J8: Conn_02x12_Odd_Even; PinHeader_2x12_P2.54mm_Horizontal
J9: Conn_01x05; PinSocket_1x05_P2.54mm_Vertical
JP1: SolderJumper_3_Bridged12; SolderJumper-3_P1.3mm_Bridged12_RoundedPad1.0x1.5mm
LOGO1, LOGO2: Logo; openithm-logo
R17, R18, R19: 33; R_Axial_DIN0207_L6.3mm_D2.5mm_P7.62mm_Horizontal
R20, R21, R22, R23, R24, R25: R_AIR; R_Axial_DIN0204_L3.6mm_D1.6mm_P5.08mm_Horizontal
U1, U2, U3, U4: 74HC4051; 74HC4051_Sparkfun_Aliexpress

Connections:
+3V3: J2.3, J8.1, JP1.3 (B), U1.2 (VCC), U1.18 (VCC), U2.2 (VCC), U2.18 (VCC), U3.2 (VCC), U3.18 (VCC), U4.2 (VCC), U4.18 (VCC)
+5V: J2.1, J7.2, JP1.1 (A)
/AIR_0: J2.9, J8.3, R22.1
/AIR_1: J2.7, J8.5, R20.1
/AIR_2: J2.5, J8.7, R24.1
/AIR_3: J2.8, J8.4, R21.1
/AIR_4: J2.6, J8.6, R25.1
/AIR_5: J2.4, J8.8, R23.1
/KEY_0: J7.10, U1.10 (Y6)
/KEY_1: J7.12, U1.12 (Y4)
/KEY_2: J7.14, U1.14 (Y2)
/KEY_3: J7.16, U1.16 (Y0)
/KEY_4: J7.18, U4.10 (Y6)
/KEY_5: J7.20, U4.12 (Y4)
/KEY_6: J7.22, U4.14 (Y2)
/KEY_7: J7.24, U4.16 (Y0)
/KEY_8: J7.9, U1.9 (Y7)
/KEY_9: J7.11, U1.11 (Y5)
/KEY_10: J7.13, U1.13 (Y3)
/KEY_11: J7.15, U1.15 (Y1)
/KEY_12: J7.17, U4.9 (Y7)
/KEY_13: J7.19, U4.11 (Y5)
/KEY_14: J7.21, U4.13 (Y3)
/KEY_15: J7.23, U4.15 (Y1)
/KEY_16: J8.9, U3.9 (Y7)
/KEY_17: J8.11, U3.11 (Y5)
/KEY_18: J8.13, U3.13 (Y3)
/KEY_19: J8.15, U3.15 (Y1)
/KEY_20: J8.17, U2.9 (Y7)
/KEY_21: J8.19, U2.11 (Y5)
/KEY_22: J8.21, U2.13 (Y3)
/KEY_23: J8.23, U2.15 (Y1)
/KEY_24: J8.10, U3.10 (Y6)
/KEY_25: J8.12, U3.12 (Y4)
/KEY_26: J8.14, U3.14 (Y2)
/KEY_27: J8.16, U3.16 (Y0)
/KEY_28: J8.18, U2.10 (Y6)
/KEY_29: J8.20, U2.12 (Y4)
/KEY_30: J8.22, U2.14 (Y2)
/KEY_31: J8.24, U2.16 (Y0)
/LED_0: J1.10, R17.2
/LED_0_OUT: J7.3, R17.1
/LED_1: J1.9, R18.2
/LED_1_OUT: J7.5, R18.1
/LED_2: J1.8, R19.2
/LED_2_OUT: J7.7, R19.1
/MUX_0: J1.4, U1.5 (S0), U2.5 (S0), U3.5 (S0), U4.5 (S0)
/MUX_1: J1.5, U1.6 (S1), U2.6 (S1), U3.6 (S1), U4.6 (S1)
/MUX_2: J1.6, U1.7 (S2), U2.7 (S2), U3.7 (S2), U4.7 (S2)
/RGB_DO: J1.7, J2.10
/RGB_DO_BUF: J7.4, J9.1
/SPARE_0: J2.14, J3.1
/SPARE_1: J3.3, J9.5
/SPARE_2: J2.13, J3.5
/SPARE_3: J1.11, J3.7
/SPARE_4: J1.12, J3.9
/SPARE_5: J1.13, J3.11
/SPARE_6: J1.14, J3.13
/TOUCH_0: J2.11, U1.4 (Z)
/TOUCH_1: J1.2, U2.4 (Z)
/TOUCH_2: J1.3, U3.4 (Z)
/TOUCH_3: J2.12, U4.4 (Z)
GND: J1.1, J2.2, J3.2, J3.4, J3.6, J3.8, J3.10, J3.12, J3.14, J7.6, J7.8, J8.2, R20.2, R21.2, R22.2, R23.2, R24.2, R25.2, U1.1 (VEE), U1.3 (GND), U1.8 (~E), U1.17 (GND), U1.19 (VEE), U2.1 (VEE), U2.3 (GND), U2.8 (~E), U2.17 (GND), U2.19 (VEE), U3.1 (VEE), U3.3 (GND), U3.8 (~E), U3.17 (GND), U3.19 (VEE), U4.1 (VEE), U4.3 (GND), U4.8 (~E), U4.17 (GND), U4.19 (VEE)
VCC: J7.1, JP1.2 (C)

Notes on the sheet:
Capacitive Touch Sensing
Teensy LC Headers
RGB lighting
OpeNITHM (32 Key Teensy ver.)
Design by VeroxZik based on work by WinEpic and mickabrig7
Connected to off-board phototransistors
IR Sensors
IR LEDs
LED #1
74HC4051 module
LED #2
LED #3
LED #4
LED #5
LED #6
IR Sensor #6
GND
VIN
3V3
Capacitive touch
PROG
External Pin Headers
Connected to off-board IR LEDs
Connected to RGB Strip
A - Anode (Long Pin) K - Cathode (Short Pin, Flat Side)
To +3.3V
If using Phototransistor: C - Collector E - Emitter If using Photodiode: C - Cathode (Short Pin, Flat Side) E - Anode (Long Pin)
IR Sensor #5
IR Sensor #4
IR Sensor #3
IR Sensor #2
IR Sensor #1
Light sensors
Connected to Copper Pads
NOTE: R_AIR is highly dependent on your IR leds and phototransistor/diodes. They may range from 10k Ohm to 2M Ohm.
Extra Pin Breakout
VCC Selection

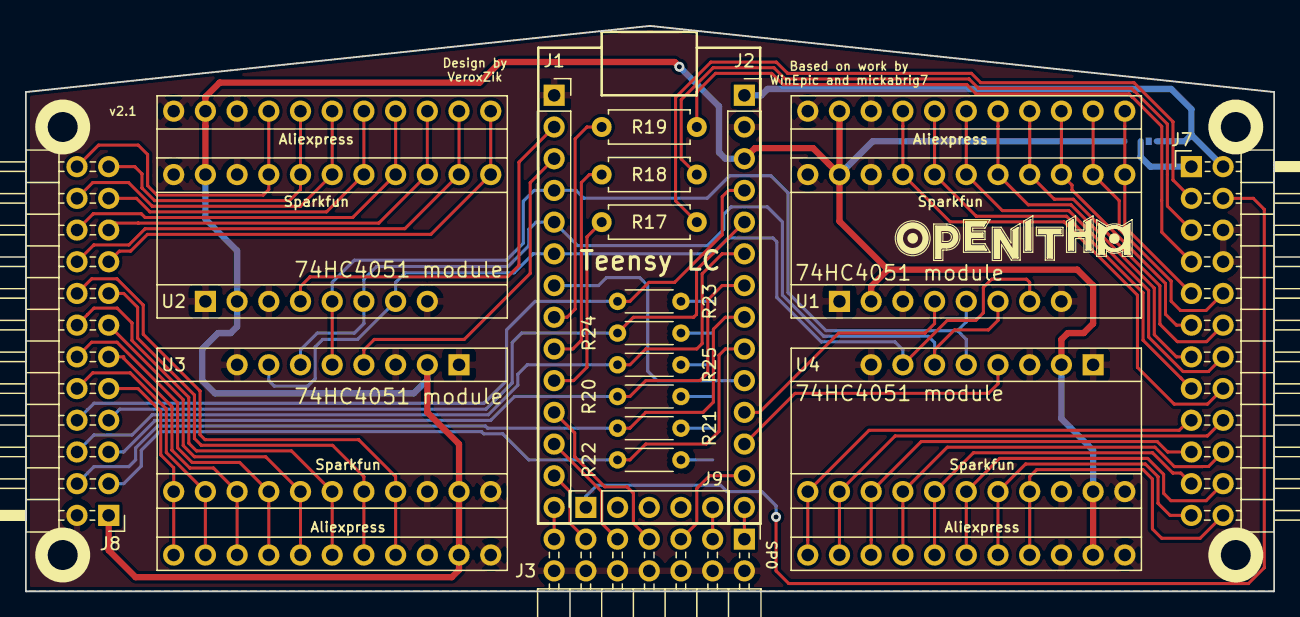
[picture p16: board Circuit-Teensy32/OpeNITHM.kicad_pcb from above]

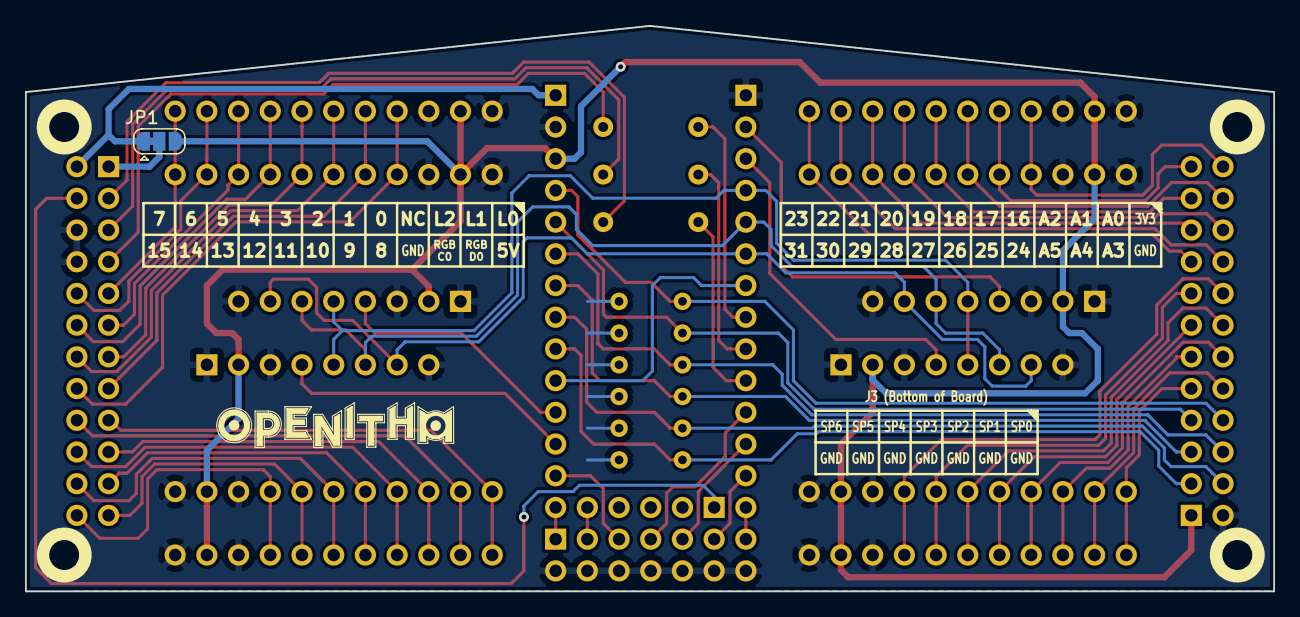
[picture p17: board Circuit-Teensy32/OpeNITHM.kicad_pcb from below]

Board: 2 copper layers, 100.0 x 45.3 mm, 26 parts (2 on the bottom side), 64 nets.

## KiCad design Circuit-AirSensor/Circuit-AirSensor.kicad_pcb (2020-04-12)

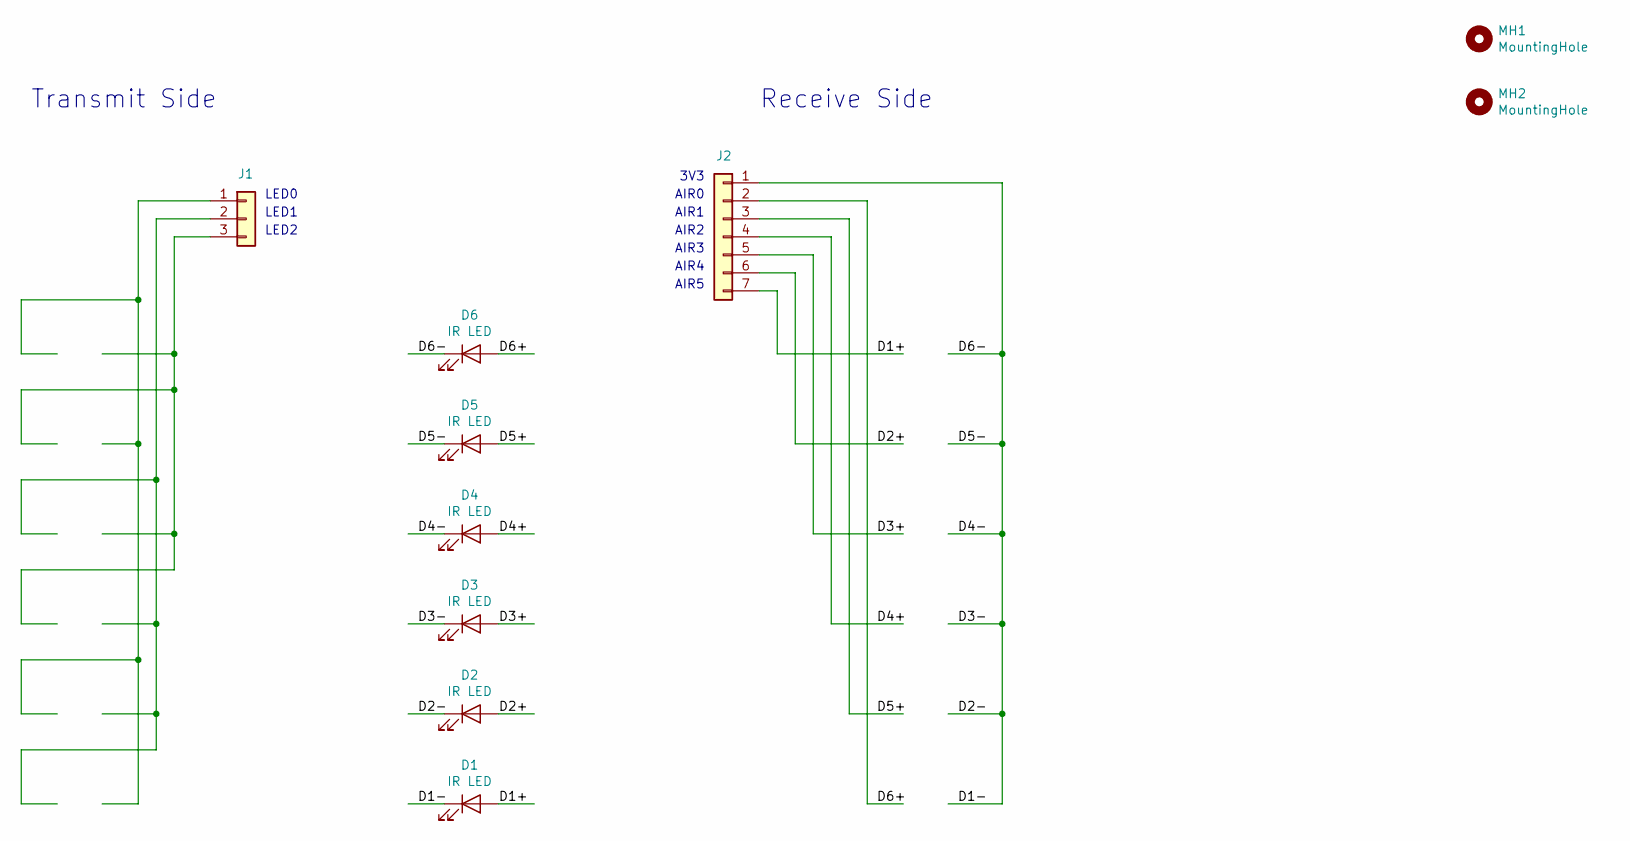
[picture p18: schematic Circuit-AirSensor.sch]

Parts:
D1, D2, D3, D4, D5, D6: IR LED; LED_D5.0mm_FlatTop
J1: Conn_01x03; SMD_3Pin
J2: Conn_01x07; SMD_7Pin
MH1, MH2: MountingHole; MountingHole_3.2mm_M3_ISO14580

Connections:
/D1+: D1.2 (A), J2.7
/D1-: D1.1 (K), D2.1 (K), D3.1 (K), D4.1 (K), D5.1 (K), D6.1 (K), J2.1
/D2+: D2.2 (A), J2.6
/D3+: D3.2 (A), J2.5
/D4+: D4.2 (A), J2.4
/D5+: D5.2 (A), J2.3
/D6+: D6.2 (A), J2.2

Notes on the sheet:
Transmit Side
LED0
LED1
LED2
AIR0
AIR1
AIR2
AIR3
AIR4
AIR5
3V3
Receive Side

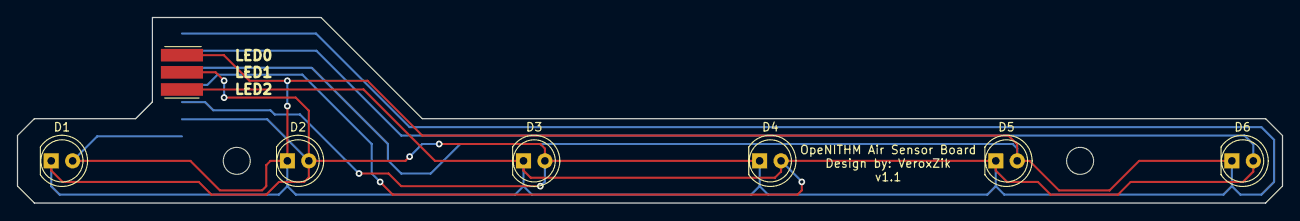
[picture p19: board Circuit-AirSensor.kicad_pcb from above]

Board: 2 copper layers, 150.0 x 22.0 mm, 10 parts (1 on the bottom side), 7 nets.

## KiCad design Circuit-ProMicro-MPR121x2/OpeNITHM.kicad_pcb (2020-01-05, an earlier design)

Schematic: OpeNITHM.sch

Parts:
C1, C2: 35V 10uF; CP_Radial_D5.0mm_P2.00mm
J1, J2, J4, J6: Conn_01x12; PinSocket_1x12_P2.54mm_Vertical
J3, J5, J9, J10: Conn_01x06; PinSocket_1x06_P2.54mm_Vertical
J7, J8: Conn_02x08_Odd_Even; PinHeader_2x08_P2.54mm_Horizontal
JP1, JP3, JP4: SolderJumper_2_Open; SolderJumper-2_P1.3mm_Open_RoundedPad1.0x1.5mm
JP2: SolderJumper_2_Bridged; SolderJumper-2_P1.3mm_Bridged_RoundedPad1.0x1.5mm
MH1, MH2, MH3, MH4: MountingHole; MountingHole_3.2mm_M3_ISO7380
R1, R2, R3: 33; R_Axial_DIN0204_L3.6mm_D1.6mm_P5.08mm_Horizontal
R4, R5, R6, R7, R8, R9: 51k; R_Axial_DIN0204_L3.6mm_D1.6mm_P5.08mm_Horizontal
U1: L4931CZ33; TO-92_Inline_Wide

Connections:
+3V3: C2.1, J3.1, J5.1, J8.2, J10.4, JP1.2, JP2.1, U1.1 (VO)
+5V: C1.1, J2.1, J7.10, J9.4, U1.3 (VI)
/AIR_0: J2.8, J8.4, R4.1
/AIR_1: J2.12, J8.6, R5.1
/AIR_2: J1.12, J8.8, R6.1
/AIR_3: J2.5, J8.10, R7.1
/AIR_4: J2.6, J8.12, R8.1
/AIR_5: J2.7, J8.14, R9.1
/KEY_0: J4.8, J7.1
/KEY_1: J4.7, J7.3
/KEY_2: J4.6, J7.5
/KEY_3: J4.5, J7.7
/KEY_4: J4.4, J7.9
/KEY_5: J4.3, J7.11
/KEY_6: J4.2, J7.13
/KEY_7: J4.1, J7.15
/KEY_8: J6.12, J8.1
/KEY_9: J6.11, J8.3
/KEY_10: J6.10, J8.5
/KEY_11: J6.9, J8.7
/KEY_12: J6.8, J8.9
/KEY_13: J6.7, J8.11
/KEY_14: J6.6, J8.13
/KEY_15: J6.5, J8.15
/LED_0: J1.11, R1.2
/LED_0_OUT: J7.2, R1.1
/LED_1: J1.10, R2.2
/LED_1_OUT: J7.4, R2.1
/LED_2: J1.9, R3.2
/LED_2_OUT: J7.6, R3.1
/RGB_CO: J2.9, J7.14
/RGB_DO: J2.11, J7.12
/SCL_H: J1.6, J9.5, JP3.1
/SCL_L: J3.3, J5.3, J10.5, JP3.2
/SDA_H: J1.5, J9.6, JP4.1
/SDA_L: J3.4, J5.4, J10.6, JP4.2
GND: C1.2, C2.2, J1.3, J1.4, J2.2, J3.6, J5.6, J7.16, J8.16, J9.3, J10.3, R4.2, R5.2, R6.2, R7.2, R8.2, R9.2, U1.2 (GND)
unnamed: J5.5, JP2.2
VCC: J2.4, JP1.1

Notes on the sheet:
Capacitive Touch Sensing
Pro Micro Headers
2019/06/27
OpeNITHM controller board
OpeNITHM (MPR121 Variant)
Design by VeroxZik
Connected to off-board phototransistors
IR Sensors
IR LEDs
LED #1
LED #2
LED #3
LED #4
LED #5
LED #6
IR Sensor #6
External Pin Headers
Connected to off-board Charlieplexed LEDs
Level Shifter
Connected to Copper Pads
Connected to RGB Strip
A - Anode (Long Pin) K - Cathode (Short Pin, Flat Side)
To +3.3V
If using Phototransistor: C - Collector E - Emitter If using Photodiode: C - Cathode (Short Pin, Flat Side) E - Anode (Long Pin)
IR Sensor #5
IR Sensor #4
IR Sensor #3
IR Sensor #2
IR Sensor #1
GND
D9/A9
RST
VCC
RAW
D20/A2
D21/A3
D18/A0
D19/A1
D14/MISO
D15/SCLK

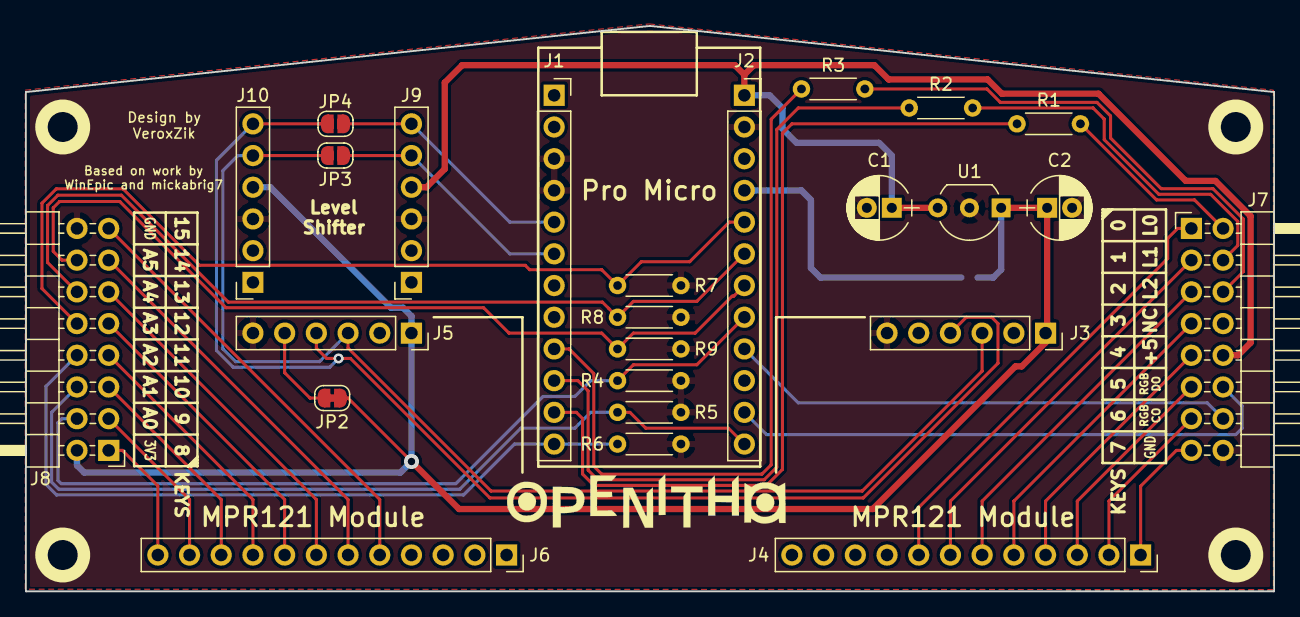
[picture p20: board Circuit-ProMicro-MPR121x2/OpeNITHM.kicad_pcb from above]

Board: 2 copper layers, 100.0 x 45.3 mm, 30 parts (1 on the bottom side), 39 nets.

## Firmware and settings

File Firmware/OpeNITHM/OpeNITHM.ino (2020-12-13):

#include "PinConfig.h"

#include "AirSensor.h"
#include "AutoTouchboard.h"
#include "LightsUtils.h"
#include "SerialLeds.h"
#include "SerialProcessor.h"
#include "USBOutput.h"

#ifdef USE_DMA_RGB
  #include <WS2812Serial.h>
  #define USE_WS2812SERIAL
#endif

#include <FastLED.h>

SerialProcessor serialProcessor;
KeyState key_states[NUM_SENSORS];

#ifndef KEY_DIVIDERS
CRGB leds[16];
#else
CRGB leds[31]; 
#endif

// Buffer for receiving serial input, either lights or config updates
byte serialBuffer[200];
// Flag that says whether the RGB strip needs to be refreshed
bool updateLeds = false;
// Flag that says whether to let serial input control the RGB strip, or make them reactively lit
bool useSerialLeds = false;
// A counter for how many loops we've run without having received any serial light updates. If
// this counter reaches a pre-defined threshold, we fall back to reactive lighting
int serialLightsCounter;

// Used for benchmarking the input polling rate
long lastMillis = 0;
// Count how many times we updated input in the last second
int pollCount = 0;
// Keep track of the maximum polling rate we achieved
int maxPollCount = 0;
// Keep track of the minimum polling rate we achieved
int minPollCount = 1000;

// The colors to light the slider keys when they're on and off in reactive lighting mode
CRGB led_on;
CRGB led_off;
CRGB divider_color;

// Whether the controller is currently active. 
bool activated = true;

AutoTouchboard *touchboard;
AirSensor *sensor;
USBOutput *output;
SerialLeds *serialLeds;

void initializeController();

/**
 * Teensy setup. Initialize FastLED and start the timer for
 * determining if we're using serial light output.
 */
void setup() {
  Serial.begin(115200);
  #ifndef KEY_DIVIDERS
  
  FastLED.addLeds<LED_TYPE, RGBPIN, LED_ORDER>(leds, 16);
  #else
  //Uncomment and tune this value if you're having power issues
  FastLED.setBrightness(170);
  FastLED.addLeds<LED_TYPE, RGBPIN, LED_ORDER>(leds, 31);
  #endif

  // Uncomment this to clear EEPROM, flash once, then comment and re-flash
  // for(int i = 0; i < 128; i++) EEPROM.put(i, 0);
  
  initializeController();
  lastMillis = millis();
}

/**
 * Do the actual setup of our classes for input and output. This is broken
 * out into a separate function so that if we update any config values over
 * serial, everything can be re-initialized without needing a Teensy reboot.
 */
void initializeController() {
  // Flash LEDs orange 3 times
  for (int i = 0; i < 3; i++)
  {
    for (CRGB& led : leds)
      led = CRGB::Orange;
      
    FastLED.show();
    delay(500);
    
    for (CRGB& led : leds)
      led = CRGB::Black;
      
    FastLED.show();
    delay(500);
  }

  // Initialize and calibrate touch sensors
  if (touchboard != NULL) delete touchboard;
  touchboard = new AutoTouchboard();

  // Initialize the serial LED processor
  if (serialLeds != NULL) delete serialLeds;
  serialLeds = new SerialLeds();

  // Initialize the reactive lighting colors, and if they're not in EEPROM, save them
  byte lightsFlag;
  EEPROM.get(67, lightsFlag);

  if (lightsFlag == LIGHTS_FLAG) {
    serialLeds->loadLights();
  } else {
    led_on = CRGB::Purple;
    led_off = CRGB::Yellow;
    divider_color = CRGB::Purple;
    serialLeds->saveLights();
  }

  // Initialize air sensor
  if (sensor != NULL) delete sensor;
  sensor = new AirSensor();
  
  FastLED.show();
  serialLightsCounter = 0;

  // Initialize the USB output
  if (output != NULL) delete output;
  output = new USBOutput();

  // Set the slider to red, it will turn the normal colors once everything is calibrated
  for (CRGB& led : leds)
    led = CRGB::Red;
    
  FastLED.show();
}

/**
 * Helps check the polling rate of the controller and benchmark its input.
 */
void checkPollRate() {
  pollCount++;
  
  if ((millis() - lastMillis) > 1000) {
    if (pollCount > maxPollCount)
      maxPollCount = pollCount;
    if (pollCount < minPollCount)
      minPollCount = pollCount;
      
    Serial.print(pollCount);
    Serial.print("\t");
    Serial.print(minPollCount);
    Serial.print("\t");
    Serial.println(maxPollCount);
    
    pollCount = 0;
    lastMillis = millis();
  }
}

/**
 * Main loop, checks all sensor states and updates the outputs as well as receive
 * serial packets for light and config updates.
 */
void loop() {
  // Uncomment this code to see benchmark in serial (in Hz)
  // checkPollRate();
  
  // Check for serial messages
  if (Serial.available() >= 100) {
    Serial.readBytes(serialBuffer, 100);
    serialProcessor.processBulk(serialBuffer);
  } else {
    serialLightsCounter++;  
  }

  // If currently paused through a config command, do not execute main loop
  if (!activated) 
    return;

  // If we haven't received any serial light updates in 5 seconds, just fallback to reactive lighting
  if (serialLightsCounter > 300) 
    useSerialLeds = false;

  // Process air sensor hand position
#if defined(USB)
#ifdef IR_SENSOR_KEY
    uint8_t airReadings = sensor->getSensorReadings();
#ifndef SERIAL_AIR_READINGS
    output->sendSensor(airReadings);
#endif
#else
    float handPosition = sensor->getHandPosition();
#ifndef SERIAL_AIR_READINGS
    output->sendSensorEvent(handPosition);
#endif
#endif
#endif

  // Scan touch keyboard and update lights
  touchboard->scan();
  int index = 0;
  
  for (int i = 0; i < 16; i++) {
#ifndef LED_REVERSE
    index = i;
#else
    index = 15 - i;
#endif

#if NUM_SENSORS == 16
    KeyState keyState = touchboard->update(i);
    
  #if !defined(SERIAL_KEY_PLOT) && defined(USB)
    if (key_states[i] != keyState)
      output->sendKeyEvent(i, keyState);
  #endif

    key_states[i] = keyState;
    
#elif NUM_SENSORS == 32
    KeyState stateTop = touchboard->update(i * 2);
    KeyState stateBot = touchboard->update(i * 2 + 1);
    KeyState keyState = stateTop + stateBot;
    
  #if !defined(SERIAL_KEY_PLOT) && defined(USB)
    if (key_states[i * 2] != stateTop)
      output->sendKeyEvent(i * 2, stateTop);
      
    if (key_states[(i * 2) + 1] != stateBot)
      output->sendKeyEvent((i * 2) + 1, stateBot);
  #endif

    key_states[i * 2] = stateTop;
    key_states[(i * 2) + 1] = stateBot;
#endif

    // handle changing key colors for non-serial LED updates
    if (!useSerialLeds) {
      // If the key is currently being held, set its color to the on color
      if (keyState > 0) {
#ifndef KEY_DIVIDERS
        leds[index] = led_on;
#else
        leds[index * 2] = led_on;
#endif
      } else {
        // If not, make it the off color
#ifndef KEY_DIVIDERS
        leds[index] = led_off;
#else
        leds[index * 2] = led_off;
#endif
      }

#ifdef KEY_DIVIDERS     
      if (index != 0)
        leds[(index * 2) - 1] = divider_color;
#endif

      updateLeds = true;  
    }
    // handle changing key colors for serial LED updates
    else {
      if (updateLeds) {
        RGBLed temp = serialLeds->getKey(i);
#ifndef KEY_DIVIDERS
        leds[index].setRGB(temp.r, temp.g, temp.b);
#else
        leds[index * 2].setRGB(temp.r, temp.g, temp.b);
        
        if (i < 15) {
          temp = serialLeds->getDivider(i);
          index = LightsUtils::getDividerIndex(i);
          leds[index].setRGB(temp.r, temp.g, temp.b);
        }
#endif
      }
    }
  }

#ifdef SERIAL_KEY_PLOT
  if (PLOT_PIN == -1) {
    for (int i = 0; i < NUM_SENSORS; i++) {
#ifdef SERIAL_RAW_VALUES
      // Print values
      Serial.print(touchboard->getRawValue(i));
#else
      // Print normalized values
      Serial.print(touchboard->getRawValue(i) - touchboard->getReleaseThresholdSingle(i));
#endif
      Serial.print("\t");
    }
    Serial.println();
  } else {
    Serial.print(touchboard->getRawValue(PLOT_PIN));
    Serial.println();
  }
#endif

  // Only update the RGB lights and send outputs once everything is calibrated
  bool airCalibrated = sensor->isCalibrated();
  bool sliderCalibrated = touchboard->isCalibrated();

  // Send update
#if !defined(SERIAL_KEY_PLOT) && !defined(SERIAL_AIR_READINGS) && defined(USB)
  if (airCalibrated && sliderCalibrated) {
    output->sendUpdate();
  }
#endif

  if (updateLeds && airCalibrated && sliderCalibrated) {
    FastLED.show();
    updateLeds = false;
  }
}

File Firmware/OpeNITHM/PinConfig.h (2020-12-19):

#include "Config.h"

#ifndef _PINCONFIG_h
#define _PINCONFIG_h

// Multiplexer pin settings
#if defined(OPENITHM_V1_0)
#define MUX_0 20
#define MUX_1 19
#define MUX_2 18
#elif defined(OPENITHM_V1_1)
#define MUX_0 2
#define MUX_1 1
#define MUX_2 0
#elif defined(OPENITHM_V2_0)
#define MUX_0 0
#define MUX_1 1
#define MUX_2 2
#elif defined(OPENITHM_V2_1)
#define MUX_0 2
#define MUX_1 3
#define MUX_2 4
#elif defined(OPENITHM_FULL_V1_0)
#define MUX_0 4
#define MUX_1 3
#define MUX_2 2
#endif

// Sensor pin settings
#if defined(OPENITHM_V1_0)
#define LED_0 16
#define LED_1 21
#define LED_2 5
#elif defined(OPENITHM_V1_1) || defined(OPENITHM_V2_0)
#define LED_0 7
#define LED_1 6
#define LED_2 5
#elif defined(OPENITHM_V2_1) || defined(OPENITHM_FULL_V1_0)
#define LED_0 8
#define LED_1 7
#define LED_2 6
#endif

#ifdef IR_SENSOR_MULTIPLEXED
#define SENSOR_IN A0
#else
#if defined(OPENITHM_V1_0)
#define AIR_SENSOR_0_PIN 10
#define AIR_SENSOR_1_PIN 11
#define AIR_SENSOR_2_PIN 12
#define AIR_SENSOR_3_PIN 6
#define AIR_SENSOR_4_PIN 8
#define AIR_SENSOR_5_PIN 9
#elif defined(OPENITHM_V1_1)
#define AIR_SENSOR_0_PIN 20
#define AIR_SENSOR_1_PIN 19
#define AIR_SENSOR_2_PIN 18
#define AIR_SENSOR_3_PIN 23
#define AIR_SENSOR_4_PIN 22
#define AIR_SENSOR_5_PIN 21
#elif defined(OPENITHM_V2_0) || defined(OPENITHM_V2_1) || defined(OPENITHM_FULL_V1_0)
#define AIR_SENSOR_0_PIN 18
#define AIR_SENSOR_1_PIN 20
#define AIR_SENSOR_2_PIN 22
#define AIR_SENSOR_3_PIN 19
#define AIR_SENSOR_4_PIN 21
#define AIR_SENSOR_5_PIN 23
#endif
#endif

// Capsense pin settings
#if defined(OPENITHM_V1_0)
#define TOUCH_0 22
#define TOUCH_1 23
#elif defined(OPENITHM_V1_1)
#define TOUCH_0 16
#define TOUCH_1 3
#elif defined(OPENITHM_V2_0)
#define TOUCH_0 16
#define TOUCH_1 3
#define TOUCH_2 4
#define TOUCH_3 15
#elif defined(OPENITHM_V2_1)
#define TOUCH_0 16
#define TOUCH_1 0
#define TOUCH_2 1
#define TOUCH_3 15
#elif defined(OPENITHM_FULL_V1_0)
#define TOUCH_0 1
#define TOUCH_1 15
#define TOUCH_2 16
#define TOUCH_3 0
#endif

// Lighting pin settings
#ifdef USE_DMA_RGB
  #define LED_TYPE    WS2812SERIAL
  #define LED_ORDER   BRG
#else
  #define LED_TYPE    WS2812B
  #define LED_ORDER   GRB
#endif

#if defined(OPENITHM_V1_0)
  #define RGBPIN 4
#elif defined(OPENITHM_V1_1) || defined(OPENITHM_V2_0)
    #ifdef USE_DMA_RGB
       #define RGBPIN 24
    #else
       #define RGBPIN 11
    #endif
#elif defined(OPENITHM_V2_1) || defined(OPENITHM_FULL_V1_0)
  #define RGBPIN 5
#endif

#endif  // _PINCONFIG_h

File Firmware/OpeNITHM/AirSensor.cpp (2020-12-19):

#include "AirSensor.h"

int ir_sensor_pins[6] = { AIR_SENSOR_0_PIN, AIR_SENSOR_1_PIN, AIR_SENSOR_2_PIN, AIR_SENSOR_3_PIN, AIR_SENSOR_4_PIN, AIR_SENSOR_5_PIN };

// Sets the output pins to switch the charlieplexed array of LEDs.
// 0 is the bottom-most LED and 5 is the top-most
void AirSensor::changeLight(int light) {
  switch (light) {
    case 0:
      pinMode(LED_0, OUTPUT);
      pinMode(LED_1, OUTPUT);
      pinMode(LED_2, INPUT);

      digitalWrite(LED_0, HIGH);
      digitalWrite(LED_1, LOW);
      digitalWrite(LED_2, LOW);
      break;
    case 1:
      pinMode(LED_0, OUTPUT);
      pinMode(LED_1, OUTPUT);
      pinMode(LED_2, INPUT);

      digitalWrite(LED_0, LOW);
      digitalWrite(LED_1, HIGH);
      digitalWrite(LED_2, LOW);
      break;
    case 2:
      pinMode(LED_0, INPUT);
      pinMode(LED_1, OUTPUT);
      pinMode(LED_2, OUTPUT);

      digitalWrite(LED_0, LOW);
      digitalWrite(LED_1, HIGH);
      digitalWrite(LED_2, LOW);
      break;
    case 3:
      pinMode(LED_0, INPUT);
      pinMode(LED_1, OUTPUT);
      pinMode(LED_2, OUTPUT);

      digitalWrite(LED_0, LOW);
      digitalWrite(LED_1, LOW);
      digitalWrite(LED_2, HIGH);
      break;
    case 4:
      pinMode(LED_0, OUTPUT);
      pinMode(LED_1, INPUT);
      pinMode(LED_2, OUTPUT);

      digitalWrite(LED_0, HIGH);
      digitalWrite(LED_1, LOW);
      digitalWrite(LED_2, LOW);
      break;
    case 5:
      pinMode(LED_0, OUTPUT);
      pinMode(LED_1, INPUT);
      pinMode(LED_2, OUTPUT);

      digitalWrite(LED_0, LOW);
      digitalWrite(LED_1, LOW);
      digitalWrite(LED_2, HIGH);
      break;
    default:
      turnOffLight();
      break;
  }
}

// Sets all output pins to high-impedance to turn off all LEDs
void AirSensor::turnOffLight() {
  pinMode(LED_0, INPUT);
  pinMode(LED_1, INPUT);
  pinMode(LED_2, INPUT);
}

uint16_t AirSensor::getValue(int sensor) {
  // Turn on light corresponding to read sensor
  changeLight(sensor);
  // Delay required because the read may occur faster than the physical light turning on
  delayMicroseconds(AIR_LED_DELAY);

  int value;

#ifndef IR_SENSOR_ANALOG
    value =  digitalRead(ir_sensor_pins[sensor]);
#else
    value =  analogRead(ir_sensor_pins[sensor]);
#endif

  // Turn the lights off when we're done reading
  turnOffLight();
  return value;
}

AirSensor::AirSensor() {
  calibrationCounter = 10;
  calibrated = false;

  for (int i = 0; i < 6; i++) {
    maxReadings[i] = 0;
  }
  
#ifndef IR_SENSOR_ANALOG
  for (int i = 0; i < 6; i++) {
    pinMode(ir_sensor_pins[i], INPUT);
  }
#endif
}

void AirSensor::analogCalibrate() {

#ifdef IR_SENSOR_ANALOG
  for (CRGB& led : leds)
    led = CRGB::Red;
    
  FastLED.show();

  // Skip some samples, for some reason the first few readings tend to give wild values that can skew min/max tracking
  for (int i = 0; i < SKIP_SAMPLES; i++) {
    for (int sensor = 5; sensor >= 0; sensor--) {
      getValue(sensor);
      touchboard -> scan();
    }
  }

  // begin calibration
  for (int i = 0; i < CALIBRATION_SAMPLES; i++) {
    for (int sensor = 5; sensor >= 0; sensor--) {
      uint16_t value = getValue(sensor);

      if (value > maxReadings[sensor])
        maxReadings[sensor] = value;
    }

    // after sweeping the LEDs, scan the touchboard to simulate the delay between
    // IR sweeps during actual gameplay so we calibrate accurately
    touchboard -> scan();
  }

  for (int i = 0; i < 6; i++) {
    thresholds[i] = (AIR_INPUT_DETECTION * maxReadings[i]);
  }
#endif

  for (CRGB& led : leds)
    led = CRGB::Green;
    
  FastLED.show();
  delay(3000);
    
  calibrated = true;
}

bool AirSensor::getSensorState(int sensor) {
  uint16_t value = getValue(sensor);

#ifdef SERIAL_AIR_READINGS  
  Serial.print(sensor);
  Serial.print("\t");
  Serial.print(value);
  Serial.print("\t");
  Serial.print(maxReadings[sensor]);
  Serial.print("\t");
  Serial.print(thresholds[sensor]);
  Serial.println();
#endif
  

#ifndef IR_SENSOR_ANALOG
  return value == LOW ? true : false;
#else
  return value < thresholds[sensor];
#endif
}

// Using data from air sensors, compute the height of the player's hand, from 0 (not present) to 1 (highest possible position).
float AirSensor::getHandPosition() {
  int highestTriggered = -1;
  
  for (int i = 5; i >= 0; i--) {
    if (getSensorState(i)) {
      if ((i + 1) > highestTriggered) {
        highestTriggered = i + 1;
      }
    }
  }

  if (calibrated) {
    return highestTriggered == -1 ? 0 : ((float) highestTriggered / 6.0f);
  } else {
    calibrationCounter--;
    
    if (calibrationCounter <= 0) {
      analogCalibrate();
      calibrated = true;
    }

    return 0;
  }
}

uint8_t AirSensor::getSensorReadings() {
  uint8_t reading = 0;

  for (int i = 5; i >= 0; i--) {
    reading |= ((int) getSensorState(i) << i);
  }

  if (calibrated) {
    return reading;
  } else {
    calibrationCounter--;
    
    if (calibrationCounter <= 0) {
      analogCalibrate();
      calibrated = true;
    }

    return 0;
  }
}

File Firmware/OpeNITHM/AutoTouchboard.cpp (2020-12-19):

#include "AutoTouchboard.h"

#if NUM_SENSORS == 32
#ifndef OPENITHM_FULL_V1_0
static const int sensorMap[] = {
  11, 3, 10, 2, 9, 1, 8, 0,
  31, 23, 30, 22, 29, 21, 28, 20,
  27, 19, 26, 18, 25, 17, 24, 16,
  15, 7, 14, 6, 13, 5, 12, 4
};
#else
 static const int sensorMap[] = {
  7, 4, 5, 6, 2, 1, 3, 0,
  31, 28, 29, 30, 26, 25, 27, 24,
  23, 20, 21, 22, 18, 17, 19, 16,
  15, 12, 13, 14, 10, 9, 11, 8
};     
#endif
#endif

void AutoTouchboard::scan() {
  // For each key, set multiplexers and poll both capacitive sensors simultaneously
  for (int i = 0; i < 8; i++) {
    digitalWrite(MUX_0, bitRead(i, 0));
    digitalWrite(MUX_1, bitRead(i, 1));
    digitalWrite(MUX_2, bitRead(i, 2));

#if NUM_SENSORS == 16
    key_values[i] = (unsigned int) touchRead(TOUCH_0);
    key_values[i + 8] = (unsigned int) touchRead(TOUCH_1);
#elif NUM_SENSORS == 32
    key_values[sensorMap[i]] = (unsigned int) touchRead(TOUCH_0); 
    key_values[sensorMap[i + 8]] = (unsigned int) touchRead(TOUCH_1);
    key_values[sensorMap[i + 16]] = (unsigned int) touchRead(TOUCH_2);
    key_values[sensorMap[i + 24]] = (unsigned int) touchRead(TOUCH_3);
#endif
  }

  /*
  for (int i = 11; i < 12; i++) {
    Serial.print(key_values[i]);
    Serial.print("\t");
  }

  for (int i = 11; i < 12; i++) {
    Serial.print(triggerThresholdsSingle[i]);
    Serial.print("\t");
  }

  Serial.println();
  */
}

void AutoTouchboard::calibrateKeys() {
  // Flash the slider red and purple so the user doesn't get near the controller during calibration
  for (int i = 0; i < 3; i++) {
    for (CRGB& led : leds)
      led = CRGB::Red;
      
    FastLED.show();
    delay(500);

    for (CRGB& led : leds)
      led = CRGB::Purple;
      
    FastLED.show();
    delay(500);
  }
  
  // take some initial readings before the main loop so we can establish baselines
  scan();
  
  int value;
  for (int i = 0; i < NUM_SENSORS; i++) {
    // determine the current thresholds for trigger
    // and release based on the configured delta threhsold
    // and the current readings
    value = key_values[i];
    
    states[i] = UNPRESSED;
    calcThresholds(i, value);
  }

  calibrated = true;
}

KeyState AutoTouchboard::update(int key) {
  // check if the button is pressed
  // keep a running record of the last X deltas and the latest readings
  int pressure = key_values[key];
  unsigned long currMillis = millis();

  if (states[key] == UNPRESSED) {
    // new press detected
    if (pressure > triggerThresholdsDouble[key]) {
      states[key] = DOUBLE_PRESS;
    } else if (pressure > triggerThresholdsSingle[key]) {
      states[key] = SINGLE_PRESS;
    }
  // new release detected
  } else if (states[key] != UNPRESSED) {
    if (pressure < releaseThresholdsSingle[key]) {
      states[key] = UNPRESSED;
    } else if (pressure < releaseThresholdsDouble[key]) {
      states[key] = SINGLE_PRESS;
    }
  }
  
#if NUM_SENSORS == 32
  if (states[key] == DOUBLE_PRESS) {
    states[key] = SINGLE_PRESS;
  }
#endif

  if (calibrated) {
    return states[key];
  } else {
    calibrationCounter--;
    
    if (calibrationCounter <= 0) {
      calibrateKeys();
      calibrated = true;
    }

    return UNPRESSED;
  }
}

uint16_t AutoTouchboard::getRawValue(int key) {
  return key_values[key];
}

uint16_t AutoTouchboard::getReleaseThresholdSingle(int key) {
  return (uint16_t)releaseThresholdsSingle[key];
}

void AutoTouchboard::calcThresholds(int key, int pressure) {
  triggerThresholdsSingle[key] = pressure + deltaThreshold;
  releaseThresholdsSingle[key] = pressure + (deltaThreshold * releaseThreshold);
  triggerThresholdsDouble[key] = triggerThresholdsSingle[key] + (deltaThreshold);
  releaseThresholdsDouble[key] = triggerThresholdsSingle[key] + (deltaThreshold * releaseThreshold);
}

AutoTouchboard::AutoTouchboard() {
  calibrationCounter = 10;
  calibrated = false;
  
  pinMode(MUX_0, OUTPUT);
  pinMode(MUX_1, OUTPUT);
  pinMode(MUX_2, OUTPUT);
}

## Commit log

2020-01-05 Initial Commit for Pro Micro + MPR121 Branch
    Must uncomment #defien USE_MPR121 first
    [OpeNITHM.kicad_pcb, OpeNITHM.sch]
2020-05-19 Updated ebay link for IR leds and phototransistor
2020-05-23 Fixed typo in PinConfig.h
    [PinConfig.h]
2020-06-04 Initial Commit of 32 key Teensy variant
    [OpeNITHM.kicad_pcb, OpeNITHM.sch]
2020-06-06 Fix Teensy v1.0 define typo
    [PinConfig.h]
2020-06-07 Initial 32 key commit
    Added 32 keys per 2.0 schematic
    Changed touch sensing to enums vs. bool and propagated changes
2020-06-09 Updated CAD files
    [Key v13.f3d, Key-Dual-2.5mm v4.f3d, Key-Dual-2.5mm.stl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]
2020-06-09 Removed LED Clamp from CAD and moved old files to CAD/Obsolete
    [Key v13.f3d, Key-US_Cust v6.f3d, Key-US_Cust.stl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]
2020-06-11 Updated Readme, added LED Support peg model
    [LED Support Peg.stl]
2020-06-14 Fixed no outputs in 32 key mode
    [OpeNITHM.ino]
2020-06-28 Create LED retaining Peg v1.f3d
    Adding source files for LED retaining peg, which was added a little bit ago.
    [LED retaining Peg v1.f3d]
2020-07-07 Updated LED Retaining Peg, Added STEP Files
    [Frame.step, Integrated Sensor Base Left.step, Key-Dual-2.5mm.step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]
2020-07-09 Update 32 key board to v2.1
    Reorganizes pins so DMA can be used, drops APA102 support, adds additional pins for complex IR LED boards.
    [OpeNITHM.kicad_pcb, OpeNITHM.sch]
2020-07-18 Changes to v2.1
    Broke out all spare pins to Teensy,
    No more solder jumper for RGB data line,
    Added solder jumper for IR LED power option (+5v by default)
    [OpeNITHM.kicad_pcb, OpeNITHM.sch]
2020-07-18 Moves 16 key board to "Depreciated" folder
    (Just use the 32 key one)
    [OpeNITHM.kicad_pcb, OpeNITHM.sch]
2020-08-10 Update 3D Printed CAD readme
2020-11-22 Fix -1 array bug
    Key 30 was being pressed every loop, making it stuck. The key divider code was accessing a negative array, overwriting other variables, causing this.
    [OpeNITHM.ino]
2020-11-27 Fixed RGB labeling on back silkscreen
    [OpeNITHM.kicad_pcb]
2020-12-08 Restore / reorganize 3D printed CAD
    Added Single Layer and Dual Layer into separate folders in STL.
    [Key-Dual-2.5mm v4.f3d, Key-Dual-2.5mm.stl, Key-Dual-3mm v2.f3d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]
2020-12-13 Fixed Serial Plot, added more debug defines
    [AirSensor.cpp, AutoTouchboard.cpp, OpeNITHM.ino]
2020-12-15 Add preliminary full PCB support based on the current prototype, and fix some air tower issues
    [AirSensor.cpp, AutoTouchboard.cpp, PinConfig.h]
